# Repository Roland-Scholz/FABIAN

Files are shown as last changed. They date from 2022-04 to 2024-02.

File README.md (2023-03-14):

# Fa Bi An
FAbulous BInary ANihilator

A simple Z80 based CP/M system. You'll find here:

- KiCad files for the pcb
- 6-chip Z80 hardware
- 64KB static RAM
- 8/16/32KB (EP)ROM, here a 2764A version is used (8KB, 12,5V pgm voltage)
- 68681 double UART operating at 115200 baud
- one serial line connects to a VT100 terminal, the 2nd one to the CP/M disk server (two TTL to RS232 converters needed)
- GAL 16V8 providing glue logic (fabian.pld, connect PIN 5 and 15 with a pice of wire)
- WinCUPL https://www.microchip.com/en-us/products/fpgas-and-plds/spld-cplds/pld-design-resources)
- CP/M-2.2 and simple BIOS source code (CP/M at $E400, BIOS at $FA00)
- Windows based build files
- Serial CP/M disk server written in Java
- 8 output pins (7 usable, OP7 toggels ROM on/off)
- 6 input pins
- I have some PCBs left, write to rolandscholz@gmx.de if you want one

FabianPCB
FabianPCBbottom
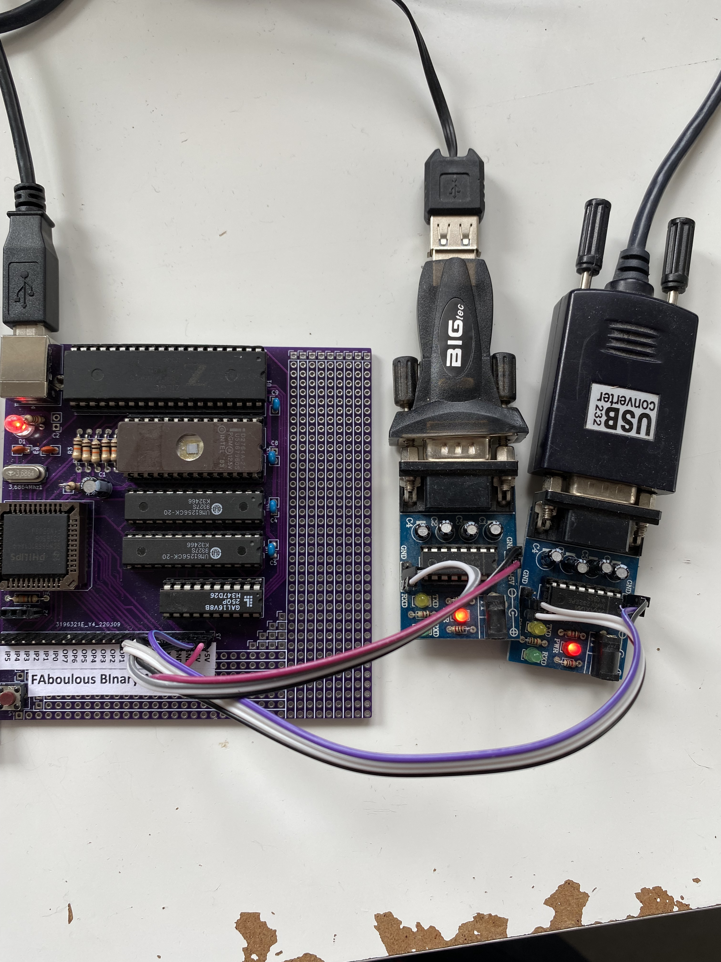
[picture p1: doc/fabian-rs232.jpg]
FabianRS232

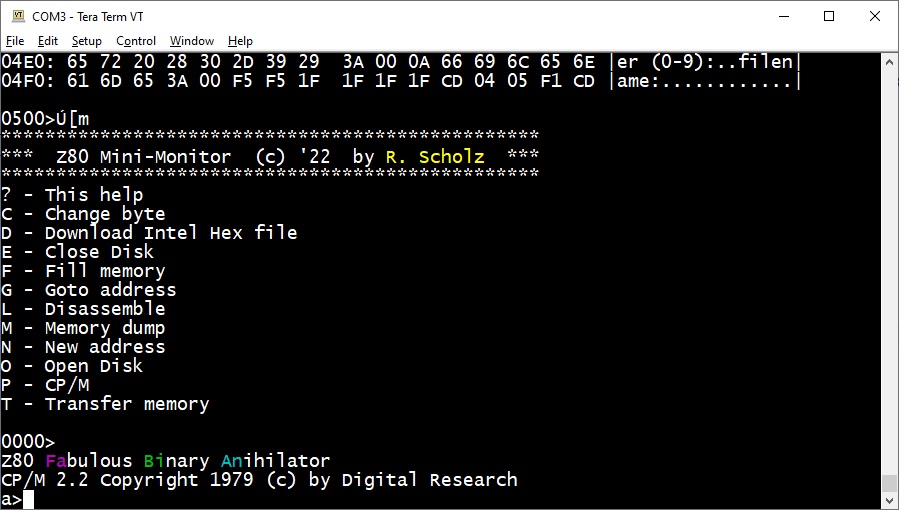
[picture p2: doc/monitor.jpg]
Monitor

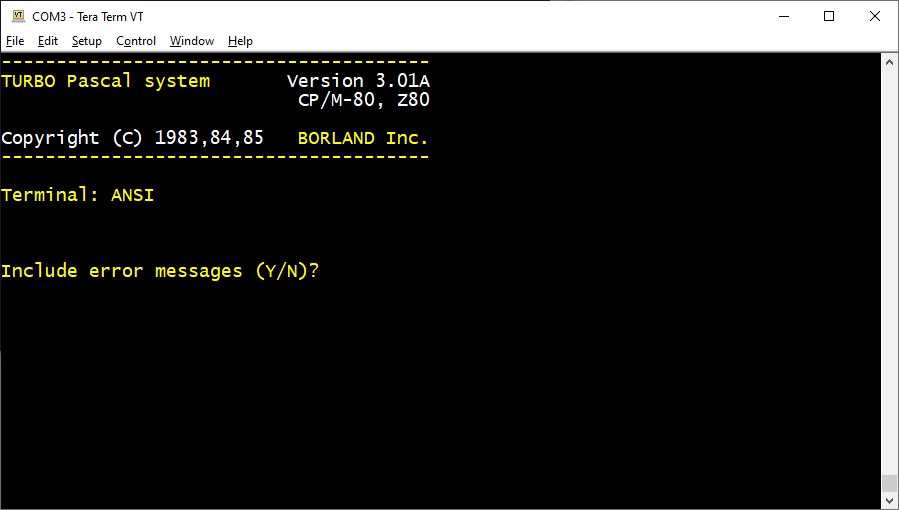
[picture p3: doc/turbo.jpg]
Turbo


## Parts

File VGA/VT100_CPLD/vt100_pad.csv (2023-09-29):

Release 8.1i - Fit P.20131013
Copyright(c) 1995-2003 Xilinx Inc. All rights reserved
9-24-2023 11:05PM
NOTE: This file is designed to be imported into a spreadsheet program
such as Microsoft Excel for viewing | printing and sorting. The comma ' | '
character is used as the data field separator.
This file is also designed to support parsing.
Input file: vt100.ngd
output file: vt100_pad.csv
Part type: xc9536
Speed grade: -15
Package: pc44
Pinout by Pin Number:
----- | ----- | ----- | ----- | ----- | ----- | ----- | ----- | ----- | -----
Pin Number | Signal Name | Pin Usage | Pin Name | Direction | IO Standard | IO Bank Number | {blank} | Slew Rate | Termination | {blank} | Voltage | Constraint
P1 | HSYNC | I/O | I/O | BIDIR
P2 | A15 | I | I/O | INPUT
P3 | WR | I | I/O | INPUT
P4 | RD | I | I/O | INPUT
P5 | pclk | GCK/I | I/O/GCK1
P6 | LOADDAT | I/O | I/O/GCK2 | BIDIR
P7 | LOADCOL | I/O | I/O/GCK3 | BIDIR
P8 | LOADAD | O | I/O | OUTPUT
P9 | CCLK | I/O | I/O | BIDIR
P10 | GND |  | GND
P11 | DE | I | I/O | INPUT
P12 | HS | I | I/O | INPUT
P13 | VS | I | I/O | INPUT
P14 | LOADSR | I/O | I/O | BIDIR
P15 | TDI |  | TDI
P16 | TMS |  | TMS
P17 | TCK |  | TCK
P18 | CRTCOE | O | I/O | OUTPUT
P19 | WE_RAM | O | I/O | OUTPUT
P20 | LOADCHR | I/O | I/O | BIDIR
P21 | VCC |  | VCCINT
P22 | CHAROE | O | I/O | OUTPUT
P23 | GND |  | GND
P24 | DISPEN | I/O | I/O | BIDIR
P25 | OE_ADR | O | I/O | OUTPUT
P26 | LOADCOLB | I/O | I/O | BIDIR
P27 | OE_DAT | O | I/O | OUTPUT
P28 | OE_RAM | O | I/O | OUTPUT
P29 | T0 | I | I/O | INPUT
P30 | TDO |  | TDO
P31 | GND |  | GND
P32 | VCC |  | VCCIO
P33 | TIE |  | I/O
P34 | TIE |  | I/O
P35 | TIE |  | I/O
P36 | TIE |  | I/O
P37 | TIE |  | I/O
P38 | TIE |  | I/O
P39 | TIE |  | I/O/GSR
P40 | TIE |  | I/O/GTS2
P41 | VCC |  | VCCINT
P42 | LCHRLINE | I/O | I/O/GTS1 | BIDIR
P43 | PIXCLKO | O | I/O | OUTPUT
P44 | VSYNC | I/O | I/O | BIDIR
To preserve the pinout above for future design iterations in
Project Navigator simply execute the (Lock Pins) process
located under the (Implement Design) process in a toolbox named
(Optional Implementation Tools) or invoke PIN2UCF from the
command line. The location constraints will be written into your
specified UCF file

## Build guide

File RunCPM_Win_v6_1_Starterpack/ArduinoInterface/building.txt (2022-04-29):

* LED.ASM (standard CP/M asm command):

A> asm led
A> load led

* LED.BAS (MBASIC v5.21):

A> mbasic led.bas

* LED.C (Hi-Tech C v3.09):

A> c -v led.c

* LED.PAS (Turbo Pascal v3.0):

A> turbo
   r
   led.pas

* PHOTO.C (Hi-Tech C v3.09):

A> c -v photo.c

* PHOTO.PAS (Turbo Pascal v3.0):

A> turbo
   r
   photo.pas

* PHOTOLED.4TH (DX-Forth v4.10):

A> dx
   include photoled.4th
   200 run

---------------
Important note:
---------------
If you experience any problems building any of the examples,
first make sure the EOL (end of line) in source files is set
to CRLF and not LF.
Git likes to change default EOL on checkout in Posix systems
(Linux, BSD, Mac OS X, etc).

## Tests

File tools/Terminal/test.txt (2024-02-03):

COM8 Standardmäßgige Seriell-über-Bluetooth-Verbindung (COM8)
COM9 Standardmäßgige Seriell-über-Bluetooth-Verbindung (COM9)
COM12 Standardmäßgige Seriell-über-Bluetooth-Verbindung (COM12)
COM4 Prolific USB-to-Serial Comm Port (COM4)
java.io.FileNotFoundException: test.txt (Das System kann die angegebene Datei nicht finden)
	at java.io.FileInputStream.open0(Native Method)
	at java.io.FileInputStream.open(FileInputStream.java:195)
	at java.io.FileInputStream.<init>(FileInputStream.java:138)
	at java.io.FileInputStream.<init>(FileInputStream.java:93)
	at Terminal.doSend(Terminal.java:71)
	at Terminal.doOperation(Terminal.java:116)
	at Terminal.<init>(Terminal.java:134)
	at Terminal.main(Terminal.java:146)

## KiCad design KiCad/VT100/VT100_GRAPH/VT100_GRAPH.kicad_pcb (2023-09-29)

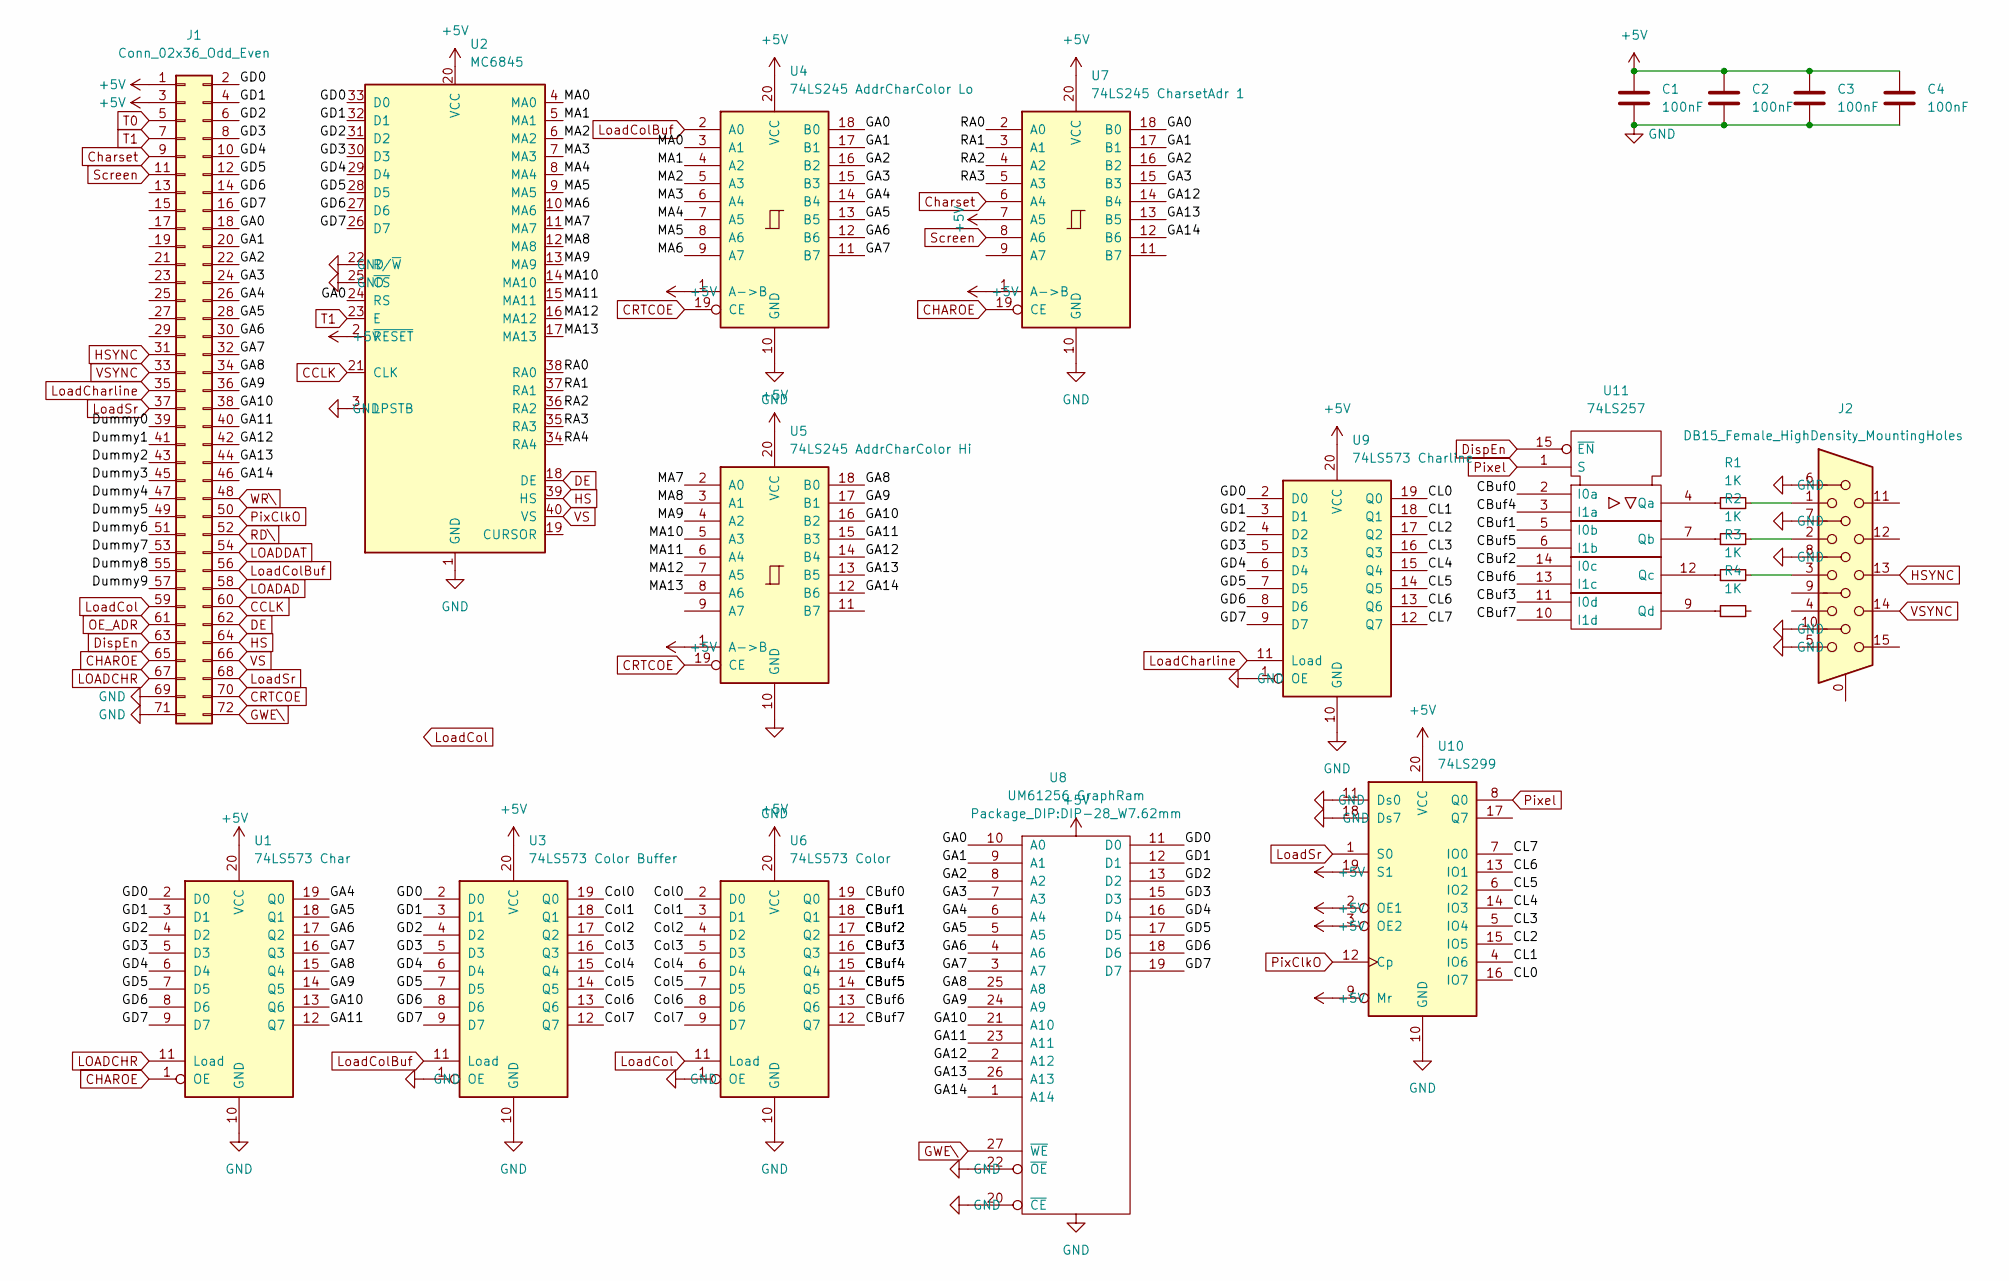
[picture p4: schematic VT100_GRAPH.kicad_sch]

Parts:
C1, C2, C3, C4: 100nF; C_Rect_L7.0mm_W2.0mm_P5.00mm
J1: Conn_02x36_Odd_Even; PinSocket_2x36_P2.54mm_Vertical
J2: DB15_Female_HighDensity_MountingHoles; DSUB-15-HD_Female_Horizontal_P2.29x1.98mm_EdgePinOffset3.03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
R1, R2, R3, R4: 1K; R_Axial_DIN0204_L3.6mm_D1.6mm_P1.90mm_Vertical
U1: 74LS573 Char; DIP-20_W7.62mm
U2: MC6845; DIP-40_W15.24mm
U3: 74LS573 Color Buffer; DIP-20_W7.62mm
U4: 74LS245 AddrCharColor Lo; DIP-20_W7.62mm
U5: 74LS245 AddrCharColor Hi; DIP-20_W7.62mm
U6: 74LS573 Color; DIP-20_W7.62mm
U7: 74LS245 CharsetAdr 1; DIP-20_W7.62mm
U8: UM61256 GraphRam; DIP-28_W7.62mm
U9: 74LS573 Charline; DIP-20_W7.62mm
U10: 74LS299; DIP-20_W7.62mm
U11: 74LS257; DIP-16_W7.62mm

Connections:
+5V: C1.1, C2.1, C3.1, C4.1, J1.1, J1.3, U1.20 (VCC), U2.2 (~RESET), U2.20 (VCC), U3.20 (VCC), U4.1 (A->B), U4.20 (VCC), U5.1 (A->B), U5.20 (VCC), U6.20 (VCC), U7.1 (A->B), U7.7 (A5), U7.20 (VCC), U8.28 (VCC), U9.20 (VCC), U10.2 (OE1), U10.3 (OE2), U10.9 (Mr), U10.19 (S1), U10.20 (VCC), U11.16 (VCC)
/CBuf0: U6.19 (Q0), U11.2 (I0a)
/CBuf1: U6.18 (Q1), U11.5 (I0b)
/CBuf2: U6.17 (Q2), U11.14 (I0c)
/CBuf3: U6.16 (Q3), U11.11 (I0d)
/CBuf4: U6.15 (Q4), U11.3 (I1a)
/CBuf5: U6.14 (Q5), U11.6 (I1b)
/CBuf6: U6.13 (Q6), U11.13 (I1c)
/CBuf7: U6.12 (Q7), U11.10 (I1d)
/CL0: U9.19 (Q0), U10.16 (IO7)
/CL1: U9.18 (Q1), U10.4 (IO6)
/CL2: U9.17 (Q2), U10.15 (IO5)
/CL3: U9.16 (Q3), U10.5 (IO4)
/CL4: U9.15 (Q4), U10.14 (IO3)
/CL5: U9.14 (Q5), U10.6 (IO2)
/CL6: U9.13 (Q6), U10.13 (IO1)
/CL7: U9.12 (Q7), U10.7 (IO0)
/Col0: U3.19 (Q0), U6.2 (D0)
/Col1: U3.18 (Q1), U6.3 (D1)
/Col2: U3.17 (Q2), U6.4 (D2)
/Col3: U3.16 (Q3), U6.5 (D3)
/Col4: U3.15 (Q4), U6.6 (D4)
/Col5: U3.14 (Q5), U6.7 (D5)
/Col6: U3.13 (Q6), U6.8 (D6)
/Col7: U3.12 (Q7), U6.9 (D7)
/Dummy0: J1.39
/Dummy1: J1.41
/Dummy2: J1.43
/Dummy3: J1.45
/Dummy4: J1.47
/Dummy5: J1.49
/Dummy6: J1.51
/Dummy7: J1.53
/Dummy8: J1.55
/Dummy9: J1.57
/GA0: J1.18, U2.24 (RS), U4.18 (B0), U7.18 (B0), U8.10 (A0)
/GA1: J1.20, U4.17 (B1), U7.17 (B1), U8.9 (A1)
/GA2: J1.22, U4.16 (B2), U7.16 (B2), U8.8 (A2)
/GA3: J1.24, U4.15 (B3), U7.15 (B3), U8.7 (A3)
/GA4: J1.26, U1.19 (Q0), U4.14 (B4), U8.6 (A4)
/GA5: J1.28, U1.18 (Q1), U4.13 (B5), U8.5 (A5)
/GA6: J1.30, U1.17 (Q2), U4.12 (B6), U8.4 (A6)
/GA7: J1.32, U1.16 (Q3), U4.11 (B7), U8.3 (A7)
/GA8: J1.34, U1.15 (Q4), U5.18 (B0), U8.25 (A8)
/GA9: J1.36, U1.14 (Q5), U5.17 (B1), U8.24 (A9)
/GA10: J1.38, U1.13 (Q6), U5.16 (B2), U8.21 (A10)
/GA11: J1.40, U1.12 (Q7), U5.15 (B3), U8.23 (A11)
/GA12: J1.42, U5.14 (B4), U7.14 (B4), U8.2 (A12)
/GA13: J1.44, U5.13 (B5), U7.13 (B5), U8.26 (A13)
/GA14: J1.46, U5.12 (B6), U7.12 (B6), U8.1 (A14)
/GD0: J1.2, U1.2 (D0), U2.33 (D0), U3.2 (D0), U8.11 (D0), U9.2 (D0)
/GD1: J1.4, U1.3 (D1), U2.32 (D1), U3.3 (D1), U8.12 (D1), U9.3 (D1)
/GD2: J1.6, U1.4 (D2), U2.31 (D2), U3.4 (D2), U8.13 (D2), U9.4 (D2)
/GD3: J1.8, U1.5 (D3), U2.30 (D3), U3.5 (D3), U8.15 (D3), U9.5 (D3)
/GD4: J1.10, U1.6 (D4), U2.29 (D4), U3.6 (D4), U8.16 (D4), U9.6 (D4)
/GD5: J1.12, U1.7 (D5), U2.28 (D5), U3.7 (D5), U8.17 (D5), U9.7 (D5)
/GD6: J1.14, U1.8 (D6), U2.27 (D6), U3.8 (D6), U8.18 (D6), U9.8 (D6)
/GD7: J1.16, U1.9 (D7), U2.26 (D7), U3.9 (D7), U8.19 (D7), U9.9 (D7)
/MA0: U2.4 (MA0), U4.3 (A1)
/MA1: U2.5 (MA1), U4.4 (A2)
/MA2: U2.6 (MA2), U4.5 (A3)
/MA3: U2.7 (MA3), U4.6 (A4)
/MA4: U2.8 (MA4), U4.7 (A5)
/MA5: U2.9 (MA5), U4.8 (A6)
/MA6: U2.10 (MA6), U4.9 (A7)
/MA7: U2.11 (MA7), U5.2 (A0)
/MA8: U2.12 (MA8), U5.3 (A1)
/MA9: U2.13 (MA9), U5.4 (A2)
/MA10: U2.14 (MA10), U5.5 (A3)
/MA11: U2.15 (MA11), U5.6 (A4)
/MA12: U2.16 (MA12), U5.7 (A5)
/MA13: U2.17 (MA13), U5.8 (A6)
/RA0: U2.38 (RA0), U7.2 (A0)
/RA1: U2.37 (RA1), U7.3 (A1)
/RA2: U2.36 (RA2), U7.4 (A2)
/RA3: U2.35 (RA3), U7.5 (A3)
/RA4: U2.34 (RA4)
CCLK: J1.60, U2.21 (CLK)
CHAROE: J1.65, U1.1 (OE), U7.19 (CE)
CRTCOE: J1.70, U4.19 (CE), U5.19 (CE)
Charset: J1.9, U7.6 (A4)
DE: J1.62, U2.18 (DE)
DispEn: J1.63, U11.15 (~EN)
GND: C1.2, C2.2, C3.2, C4.2, J1.69, J1.71, J2.5, J2.6, J2.7, J2.8, J2.10, U1.10 (GND), U2.1 (GND), U2.3 (LPSTB), U2.22 (R/~W), U2.25 (~CS), U3.1 (OE), U3.10 (GND), U4.10 (GND), U5.10 (GND), U6.1 (OE), U6.10 (GND), U7.10 (GND), U8.14 (GND), U8.20 (~CE), U8.22 (~OE), U9.1 (OE), U9.10 (GND), U10.10 (GND), U10.11 (Ds0), U10.18 (Ds7), U11.8 (GND)
GWE\: J1.72, U8.27 (~WE)
HS: J1.64, U2.39 (HS)
HSYNC: J1.31, J2.13
LOADAD: J1.58
LOADCHR: J1.67, U1.11 (Load)
LOADDAT: J1.54
LoadCharline: J1.35, U9.11 (Load)
LoadCol: J1.59, U6.11 (Load)
LoadColBuf: J1.56, U3.11 (Load), U4.2 (A0)
LoadSr: J1.37, J1.68, U10.1 (S0)
unnamed: J2.1, R1.2
unnamed: J2.2, R2.2
unnamed: J2.3, R3.2
unnamed: R1.1, U11.4 (Qa)
unnamed: R2.1, U11.7 (Qb)
unnamed: R3.1, U11.12 (Qc)
unnamed: R4.1, U11.9 (Qd)
OE_ADR: J1.61
PixClkO: J1.50, U10.12 (Cp)
Pixel: U10.8 (Q0), U11.1 (S)
RD\: J1.52
Screen: J1.11, U7.8 (A6)
T0: J1.5
T1: J1.7, U2.23 (E)
VS: J1.66, U2.40 (VS)
VSYNC: J1.33, J2.14
WR\: J1.48

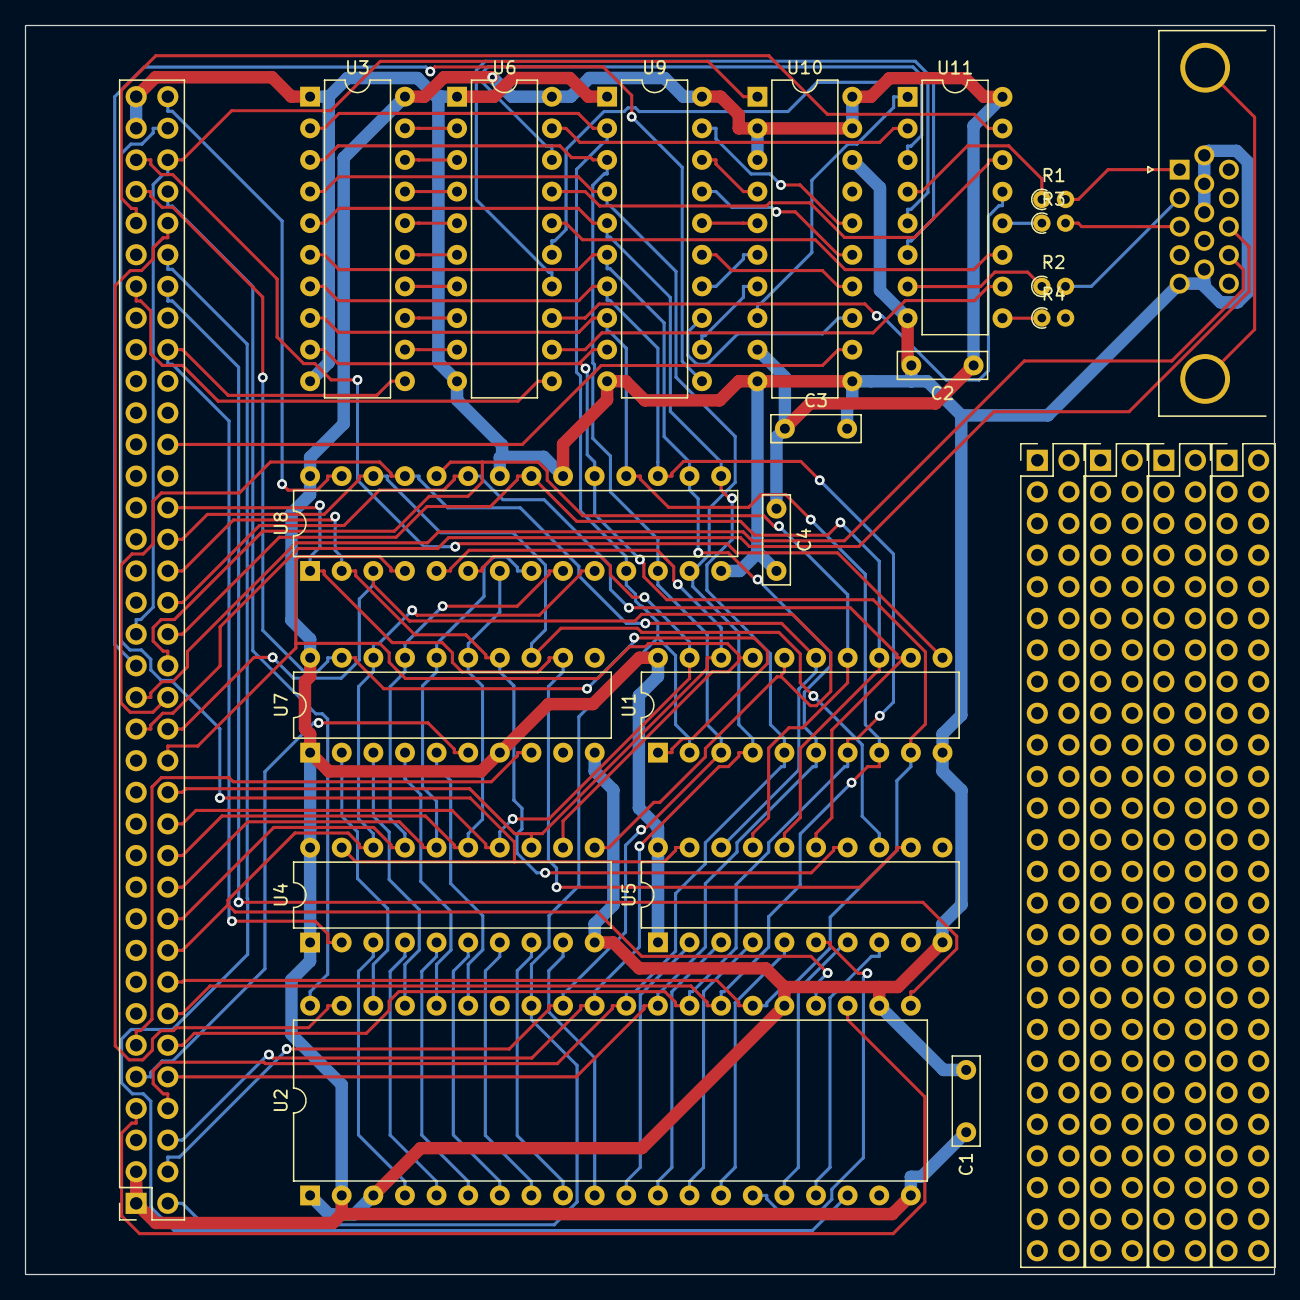
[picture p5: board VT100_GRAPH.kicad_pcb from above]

Board: 2 copper layers, 100.3 x 100.3 mm, 21 parts (0 on the bottom side), 94 nets.

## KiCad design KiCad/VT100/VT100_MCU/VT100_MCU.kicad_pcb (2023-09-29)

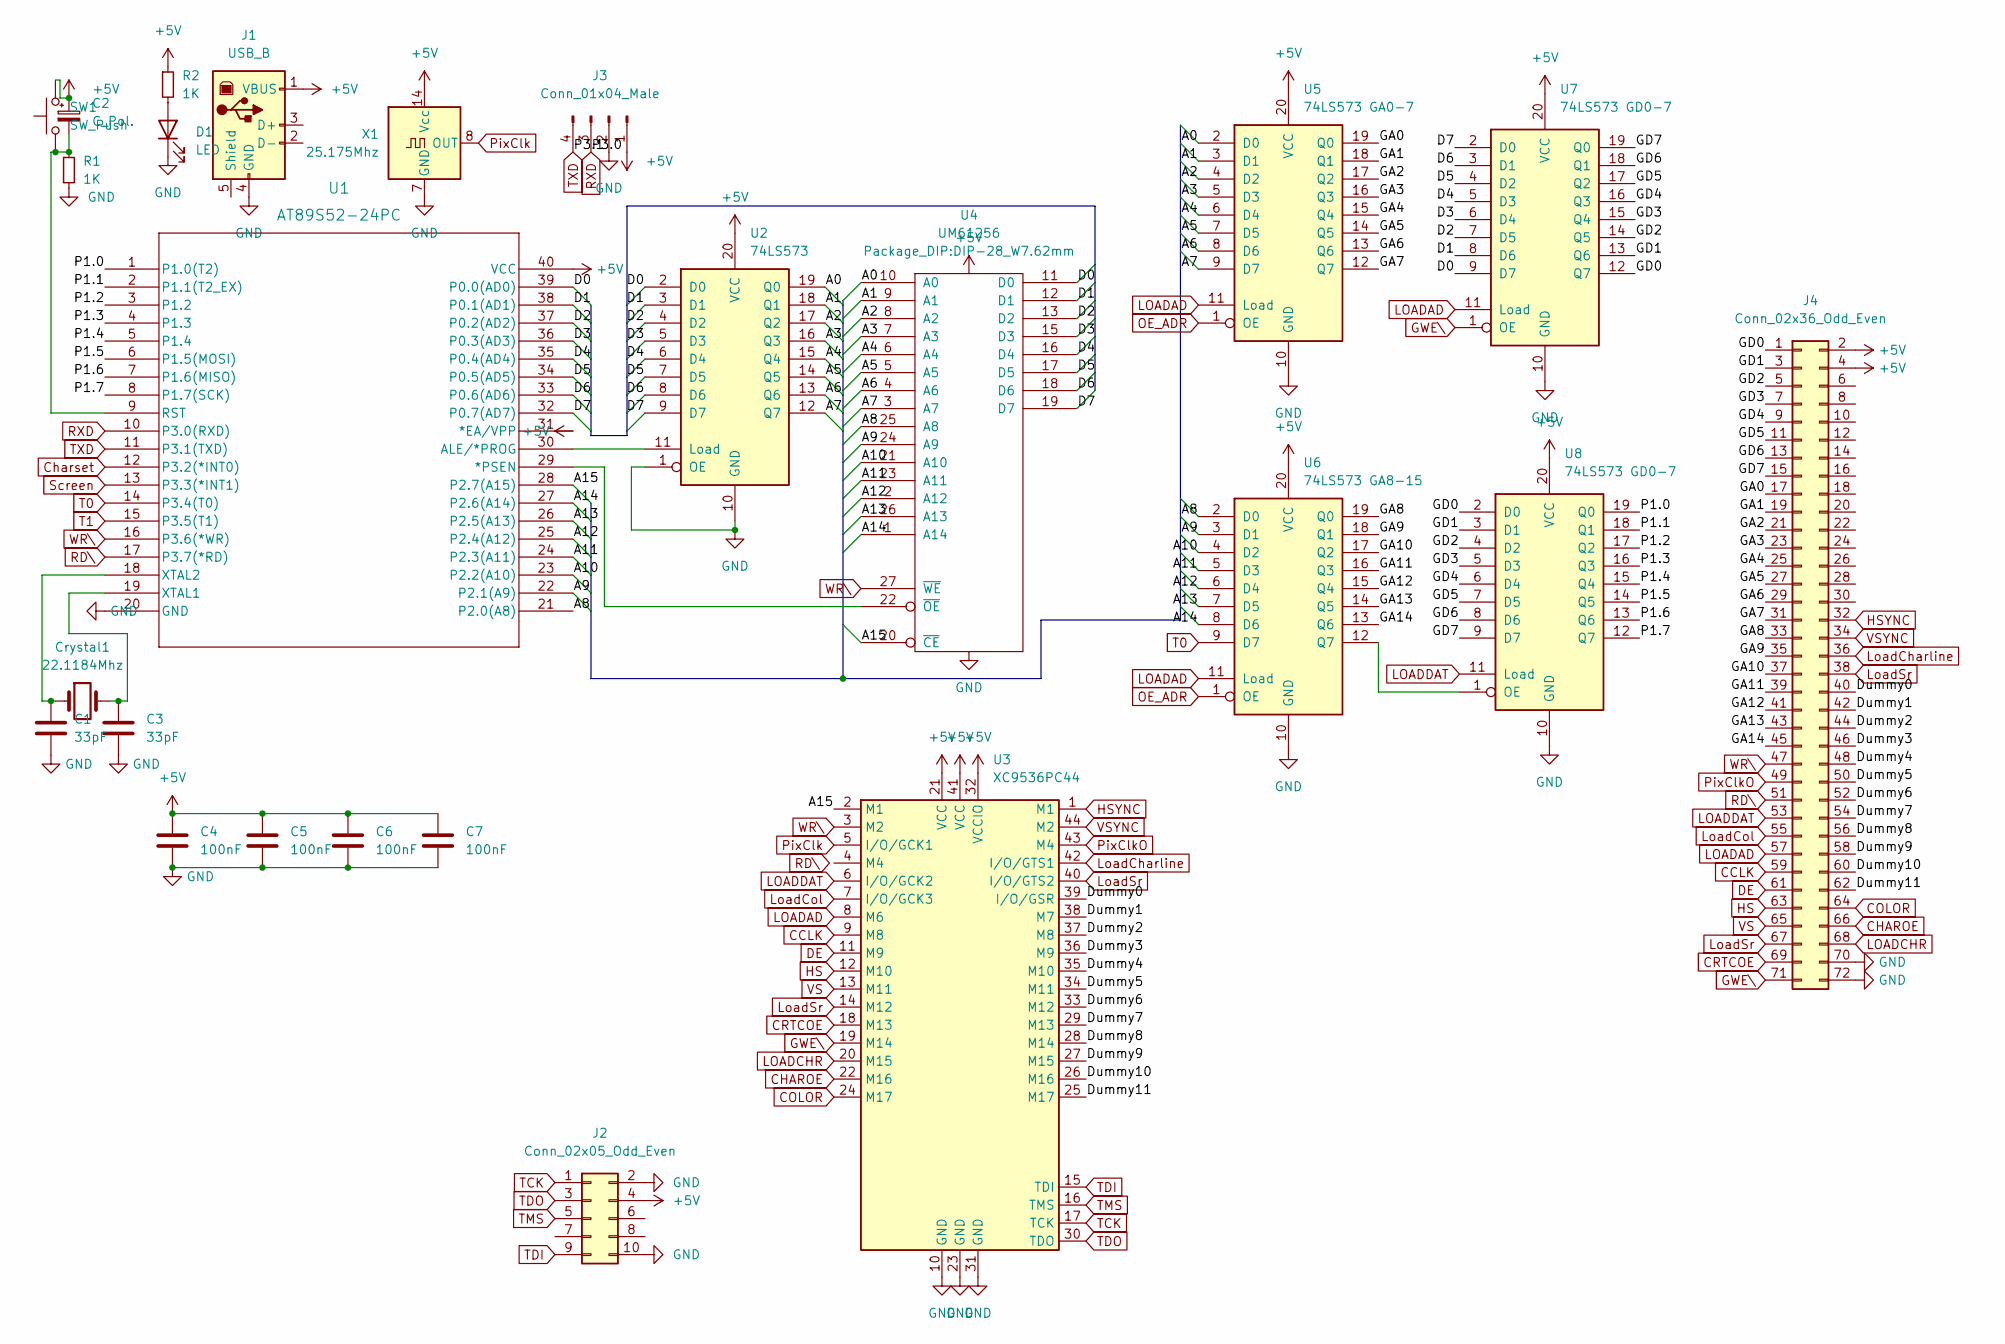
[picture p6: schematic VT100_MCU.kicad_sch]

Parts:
C1, C3: 33pF; PinHeader_1x02_P2.54mm_Vertical
C2: C_Pol.; CP_Radial_D5.0mm_P2.50mm
C4, C5, C6, C7: 100nF; PinHeader_1x02_P2.54mm_Vertical
Crystal1: 22.1184Mhz; Crystal_HC18-U_Vertical
D1: LED; LED_D5.0mm
J1: USB_B; USB_B_Lumberg_2411_02_Horizontal
J2: Conn_02x05_Odd_Even; PinHeader_2x05_P2.54mm_Vertical
J3: Conn_01x04_Male; PinHeader_1x04_P2.54mm_Vertical
J4: Conn_02x36_Odd_Even; PinSocket_2x36_P2.54mm_Horizontal
R1, R2: 1K; R_Axial_DIN0204_L3.6mm_D1.6mm_P1.90mm_Vertical
SW1: SW_Push; C_Rect_L7.5mm_W6.5mm_P5.00mm
U1: AT89S52-24PC; DIP-40_W15.24mm
U2: 74LS573; DIP-20_W7.62mm
U3: XC9536PC44; PLCC-44_THT-Socket
U4: UM61256; DIP-28_W7.62mm
U5: 74LS573 GA0-7; DIP-20_W7.62mm
U6: 74LS573 GA8-15; DIP-20_W7.62mm
U7, U8: 74LS573 GD0-7; DIP-20_W7.62mm
X1: 25.175Mhz; Oscillator_DIP-14

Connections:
+5V: C2.1, C4.1, C5.1, C6.1, C7.1, J1.1 (VBUS), J2.4, J3.1, J4.2, J4.4, R2.1, SW1.2, U1.31 (*EA/VPP), U1.40 (VCC), U2.20 (VCC), U3.21 (VCC), U3.32 (VCCIO), U3.41 (VCC), U4.28 (VCC), U5.20 (VCC), U6.20 (VCC), U7.20 (VCC), U8.20 (VCC), X1.14 (Vcc)
/A0: U2.19 (Q0), U4.10 (A0), U5.2 (D0)
/A1: U2.18 (Q1), U4.9 (A1), U5.3 (D1)
/A2: U2.17 (Q2), U4.8 (A2), U5.4 (D2)
/A3: U2.16 (Q3), U4.7 (A3), U5.5 (D3)
/A4: U2.15 (Q4), U4.6 (A4), U5.6 (D4)
/A5: U2.14 (Q5), U4.5 (A5), U5.7 (D5)
/A6: U2.13 (Q6), U4.4 (A6), U5.8 (D6)
/A7: U2.12 (Q7), U4.3 (A7), U5.9 (D7)
/A8: U1.21 (P2.0(A8)), U4.25 (A8), U6.2 (D0)
/A9: U1.22 (P2.1(A9)), U4.24 (A9), U6.3 (D1)
/A10: U1.23 (P2.2(A10)), U4.21 (A10), U6.4 (D2)
/A11: U1.24 (P2.3(A11)), U4.23 (A11), U6.5 (D3)
/A12: U1.25 (P2.4(A12)), U4.2 (A12), U6.6 (D4)
/A13: U1.26 (P2.5(A13)), U4.26 (A13), U6.7 (D5)
/A14: U1.27 (P2.6(A14)), U4.1 (A14), U6.8 (D6)
/A15: U1.28 (P2.7(A15)), U3.2 (M1), U4.20 (~CE)
/D0: U1.39 (P0.0(AD0)), U2.2 (D0), U4.11 (D0), U7.9 (D7)
/D1: U1.38 (P0.1(AD1)), U2.3 (D1), U4.12 (D1), U7.8 (D6)
/D2: U1.37 (P0.2(AD2)), U2.4 (D2), U4.13 (D2), U7.7 (D5)
/D3: U1.36 (P0.3(AD3)), U2.5 (D3), U4.15 (D3), U7.6 (D4)
/D4: U1.35 (P0.4(AD4)), U2.6 (D4), U4.16 (D4), U7.5 (D3)
/D5: U1.34 (P0.5(AD5)), U2.7 (D5), U4.17 (D5), U7.4 (D2)
/D6: U1.33 (P0.6(AD6)), U2.8 (D6), U4.18 (D6), U7.3 (D1)
/D7: U1.32 (P0.7(AD7)), U2.9 (D7), U4.19 (D7), U7.2 (D0)
/Dummy0: J4.40, U3.39 (I/O/GSR)
/Dummy1: J4.42, U3.38 (M7)
/Dummy2: J4.44, U3.37 (M8)
/Dummy3: J4.46, U3.36 (M9)
/Dummy4: J4.48, U3.35 (M10)
/Dummy5: J4.50, U3.34 (M11)
/Dummy6: J4.52, U3.33 (M12)
/Dummy7: J4.54, U3.29 (M13)
/Dummy8: J4.56, U3.28 (M14)
/Dummy9: J4.58, U3.27 (M15)
/Dummy10: J4.60, U3.26 (M16)
/GA0: J4.17, U5.19 (Q0)
/GA1: J4.19, U5.18 (Q1)
/GA2: J4.21, U5.17 (Q2)
/GA3: J4.23, U5.16 (Q3)
/GA4: J4.25, U5.15 (Q4)
/GA5: J4.27, U5.14 (Q5)
/GA6: J4.29, U5.13 (Q6)
/GA7: J4.31, U5.12 (Q7)
/GA8: J4.33, U6.19 (Q0)
/GA9: J4.35, U6.18 (Q1)
/GA10: J4.37, U6.17 (Q2)
/GA11: J4.39, U6.16 (Q3)
/GA12: J4.41, U6.15 (Q4)
/GA13: J4.43, U6.14 (Q5)
/GA14: J4.45, U6.13 (Q6)
/GD0: J4.1, U7.12 (Q7), U8.2 (D0)
/GD1: J4.3, U7.13 (Q6), U8.3 (D1)
/GD2: J4.5, U7.14 (Q5), U8.4 (D2)
/GD3: J4.7, U7.15 (Q4), U8.5 (D3)
/GD4: J4.9, U7.16 (Q3), U8.6 (D4)
/GD5: J4.11, U7.17 (Q2), U8.7 (D5)
/GD6: J4.13, U7.18 (Q1), U8.8 (D6)
/GD7: J4.15, U7.19 (Q0), U8.9 (D7)
/P1.0: U1.1 (P1.0(T2)), U8.19 (Q0)
/P1.1: U1.2 (P1.1(T2_EX)), U8.18 (Q1)
/P1.2: U1.3 (P1.2), U8.17 (Q2)
/P1.3: U1.4 (P1.3), U8.16 (Q3)
/P1.4: U1.5 (P1.4), U8.15 (Q4)
/P1.5: U1.6 (P1.5(MOSI)), U8.14 (Q5)
/P1.6: U1.7 (P1.6(MISO)), U8.13 (Q6)
/P1.7: U1.8 (P1.7(SCK)), U8.12 (Q7)
CCLK: J4.59, U3.9 (M8)
CHAROE: J4.66, U3.22 (M16)
CRTCOE: J4.69, U3.18 (M13)
Charset: J4.10, U1.12 (P3.2(*INT0))
DE: J4.61, U3.11 (M9)
DispEn: J4.64, U3.24 (M17)
GND: C1.2, C3.2, C4.2, C5.2, C6.2, C7.2, D1.1 (K), J1.4 (GND), J2.2, J2.10, J3.2, J4.70, J4.72, R1.2, U1.20 (GND), U2.1 (OE), U2.10 (GND), U3.10 (GND), U3.23 (GND), U3.31 (GND), U4.14 (GND), U5.10 (GND), U6.10 (GND), U7.10 (GND), U8.10 (GND), X1.7 (GND)
GWE\: J4.71, U3.19 (M14), U7.1 (OE)
HS: J4.63, U3.12 (M10)
HSYNC: J4.32, U3.1 (M1)
LOADAD: J4.57, U3.8 (M6), U5.11 (Load), U6.11 (Load), U7.11 (Load)
LOADCHR: J4.68, U3.20 (M15)
LOADDAT: J4.53, U3.6 (I/O/GCK2), U8.11 (Load)
LoadCharline: J4.36, U3.42 (I/O/GTS1)
LoadCol: J4.55, U3.7 (I/O/GCK3)
LoadSr: J4.38, J4.67, U3.14 (M12), U3.40 (I/O/GTS2)
unnamed: C1.1, Crystal1.1, U1.18 (XTAL2)
unnamed: C2.2, R1.1, SW1.1, U1.9 (RST)
unnamed: C3.1, Crystal1.2, U1.19 (XTAL1)
unnamed: D1.2 (A), R2.2
unnamed: U1.29 (*PSEN), U4.22 (~OE)
unnamed: U1.30 (ALE/*PROG), U2.11 (Load)
unnamed: U6.12 (Q7), U8.1 (OE)
PixClk: U3.5 (I/O/GCK1), X1.8 (OUT)
PixClkO: J4.49, U3.43 (M4)
RD\: J4.51, U1.17 (P3.7(*RD)), U3.4 (M4)
RXD: J3.3, U1.10 (P3.0(RXD))
Screen: J4.12, U1.13 (P3.3(*INT1))
T0: J4.6, U1.14 (P3.4(T0)), U6.9 (D7)
T1: J4.8, U1.15 (P3.5(T1))
TCK: J2.1, U3.17 (TCK)
TDI: J2.9, U3.15 (TDI)
TDO: J2.3, U3.30 (TDO)
TMS: J2.5, U3.16 (TMS)
TXD: J3.4, U1.11 (P3.1(TXD))
VS: J4.65, U3.13 (M11)
VSYNC: J4.34, U3.44 (M2)
WR\: J4.47, U1.16 (P3.6(*WR)), U3.3 (M2), U4.27 (~WE)

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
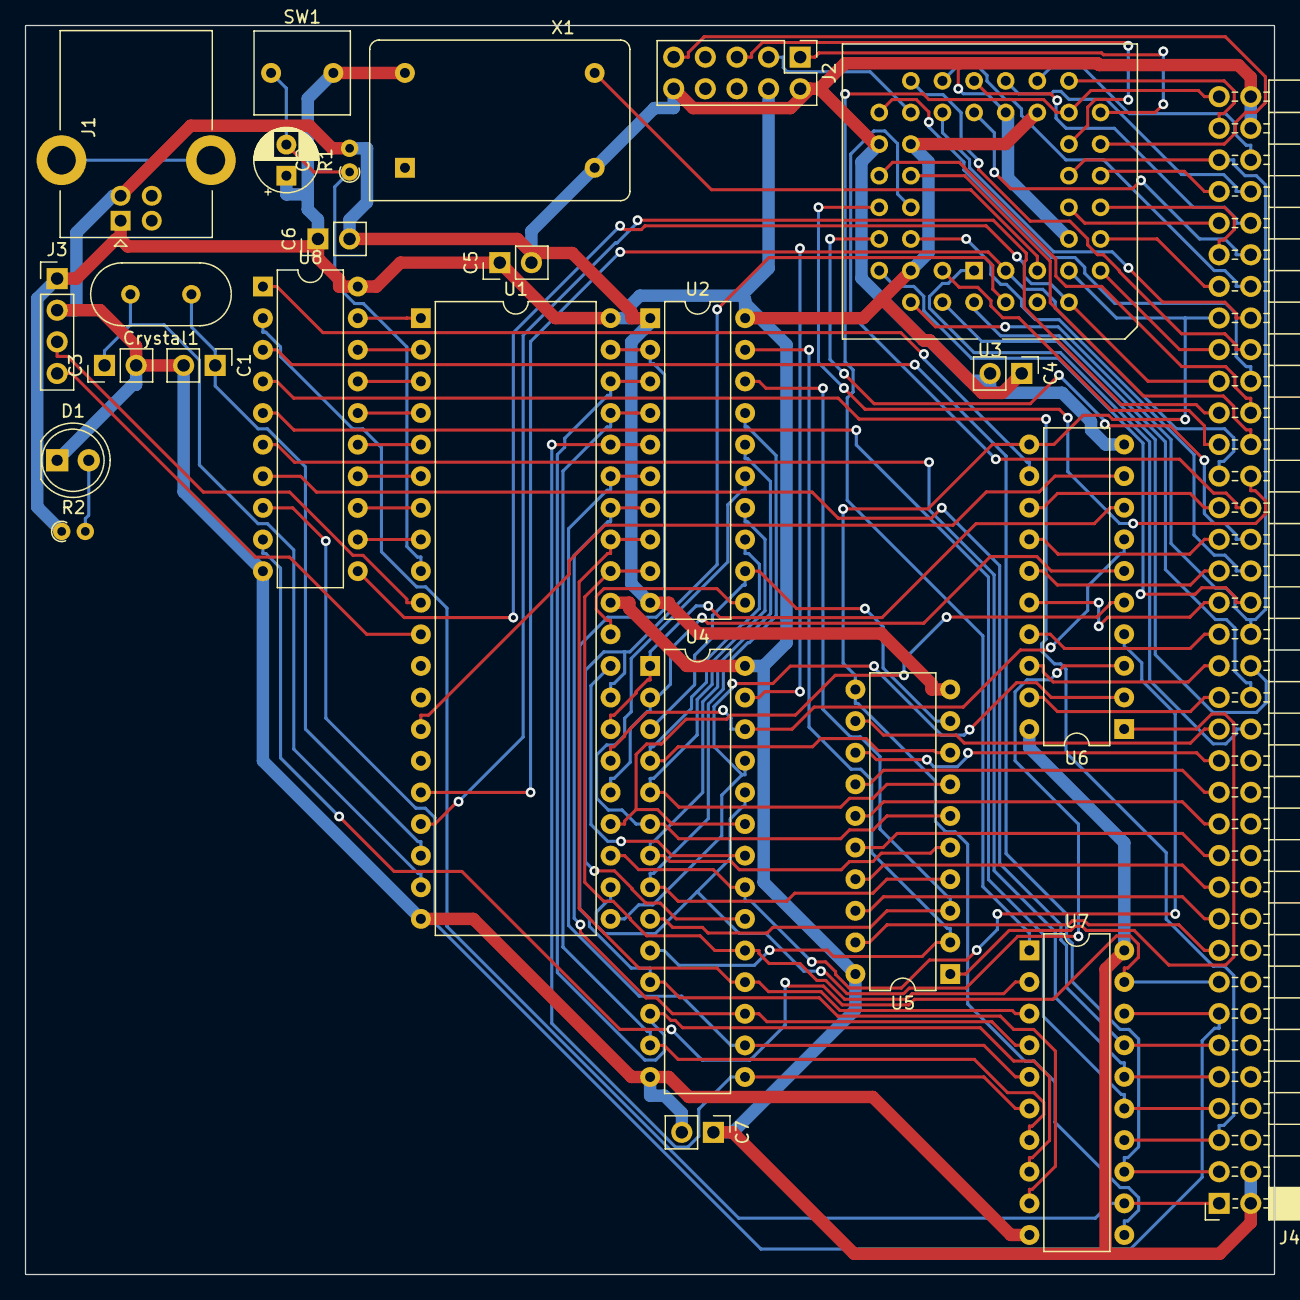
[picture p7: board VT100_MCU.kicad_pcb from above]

Board: 2 copper layers, 100.3 x 100.3 mm, 25 parts (0 on the bottom side), 106 nets.

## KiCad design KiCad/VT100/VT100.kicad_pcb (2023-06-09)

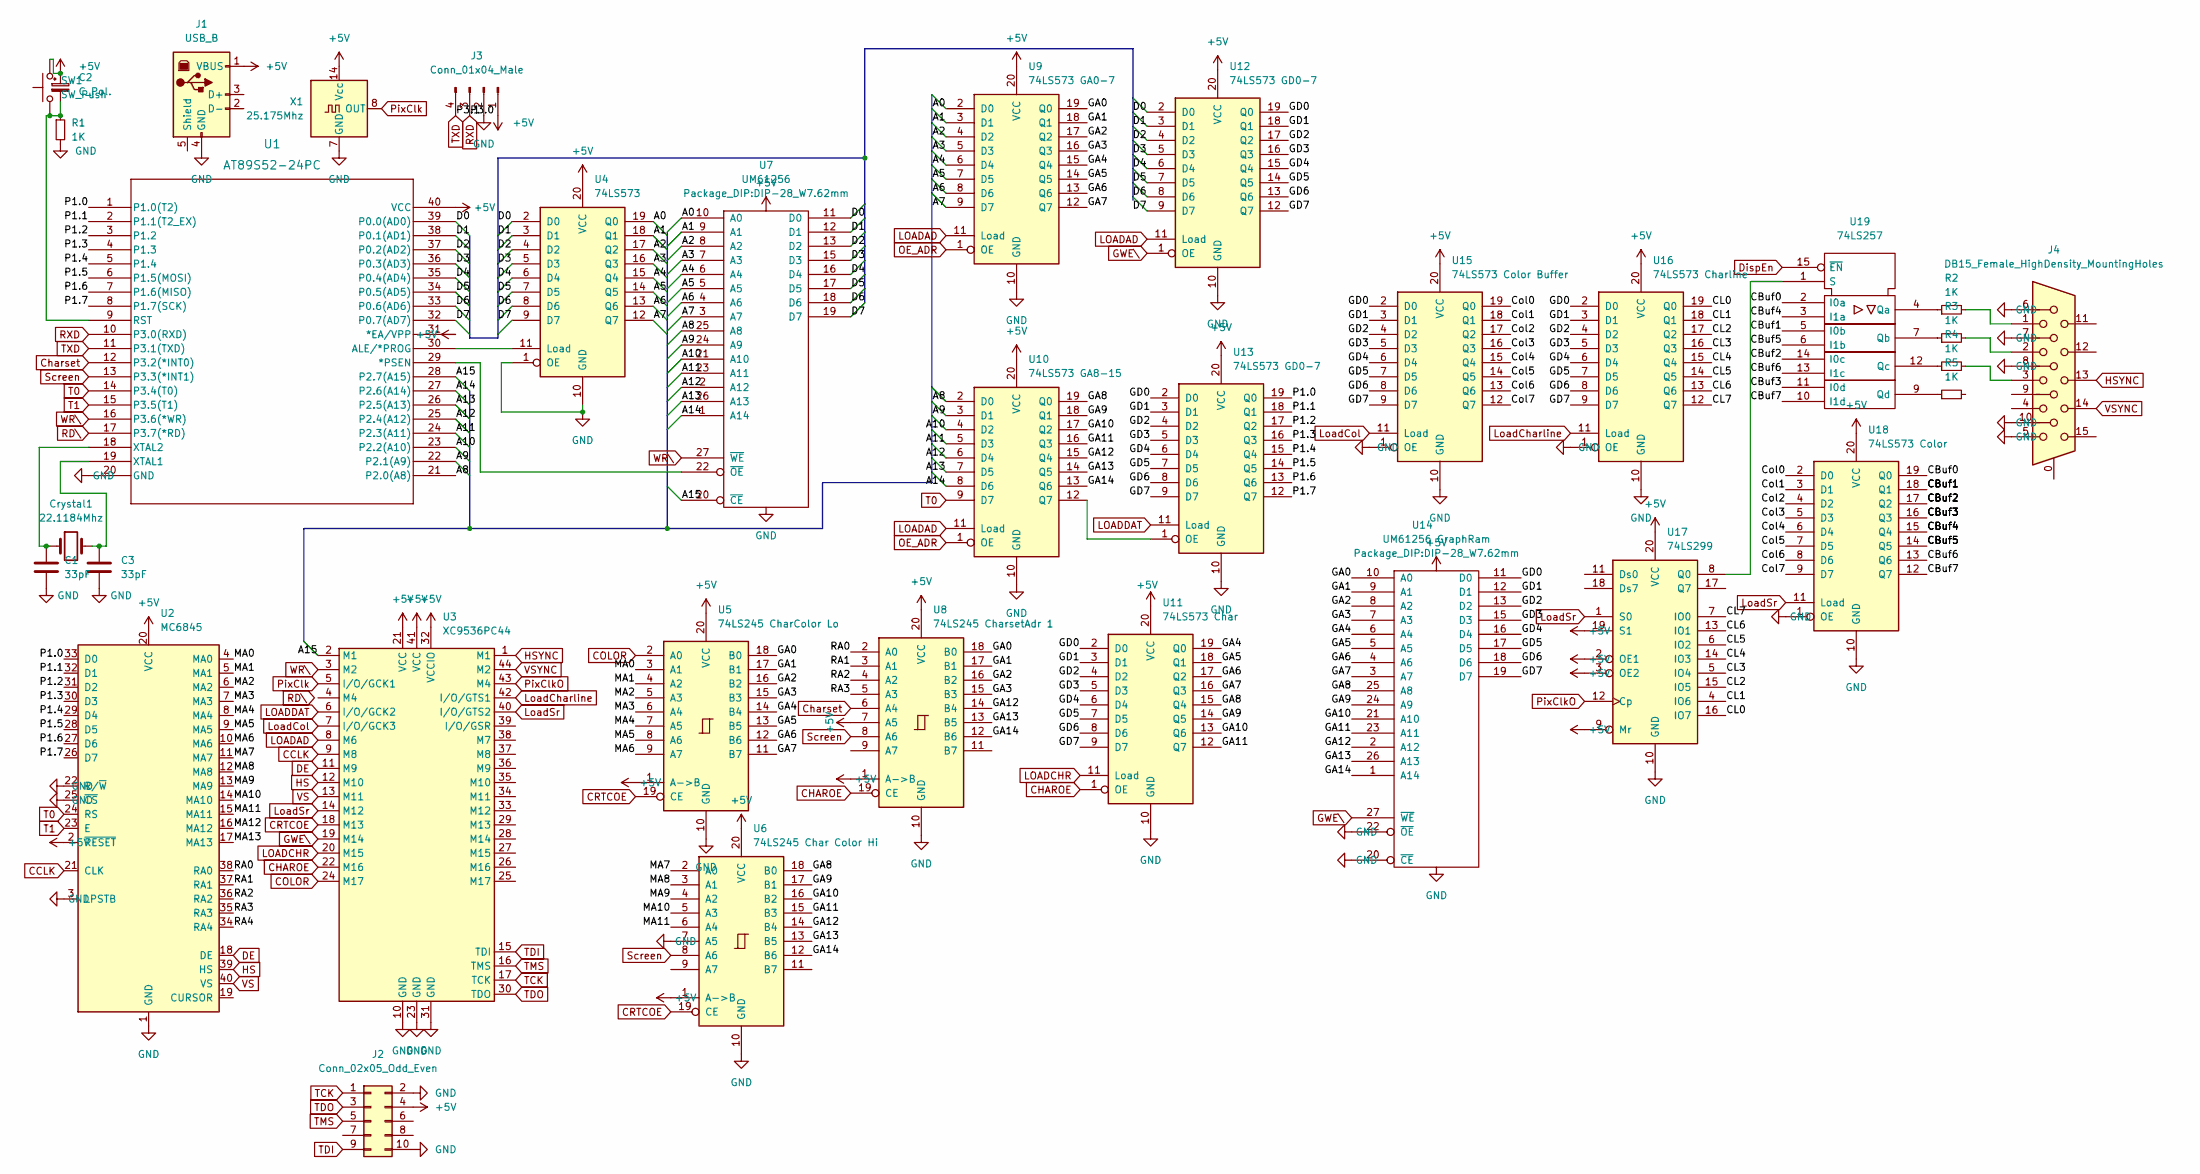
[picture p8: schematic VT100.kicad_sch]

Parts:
C1, C3: 33pF; PinHeader_1x02_P2.54mm_Vertical
C2: C_Pol.; CP_Radial_D5.0mm_P2.50mm
Crystal1: 22.1184Mhz; Crystal_HC18-U_Vertical
J1: USB_B; USB_B_Lumberg_2411_02_Horizontal
J2: Conn_02x05_Odd_Even; PinHeader_2x05_P2.54mm_Vertical
J3: Conn_01x04_Male; PinHeader_1x04_P2.54mm_Vertical
J4: DB15_Female_HighDensity_MountingHoles; DSUB-15-HD_Female_Horizontal_P2.29x1.98mm_EdgePinOffset3.03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
R1, R2, R3, R4, R5: 1K; R_Axial_DIN0204_L3.6mm_D1.6mm_P1.90mm_Vertical
SW1: SW_Push; C_Rect_L7.5mm_W6.5mm_P5.00mm
U1: AT89S52-24PC; DIP-40_W15.24mm
U2: MC6845; DIP-40_W15.24mm
U3: XC9536PC44; PLCC-44_THT-Socket
U4: 74LS573; DIP-20_W7.62mm
U5: 74LS245 CharColor Lo; DIP-20_W7.62mm
U6: 74LS245 Char Color Hi; DIP-20_W7.62mm
U7: UM61256; DIP-28_W7.62mm
U8: 74LS245 CharsetAdr 1; DIP-20_W7.62mm
U9: 74LS573 GA0-7; DIP-20_W7.62mm
U10: 74LS573 GA8-15; DIP-20_W7.62mm
U11: 74LS573 Char; DIP-20_W7.62mm
U12, U13: 74LS573 GD0-7; DIP-20_W7.62mm
U14: UM61256 GraphRam; DIP-28_W7.62mm
U15: 74LS573 Color Buffer; DIP-20_W7.62mm
U16: 74LS573 Charline; DIP-20_W7.62mm
U17: 74LS299; DIP-20_W7.62mm
U18: 74LS573 Color; DIP-20_W7.62mm
U19: 74LS257; DIP-16_W7.62mm
X1: 25.175Mhz; Oscillator_DIP-14

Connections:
+5V: C2.1, J1.1 (VBUS), J2.4, J3.1, SW1.2, U1.31 (*EA/VPP), U1.40 (VCC), U2.2 (~RESET), U2.20 (VCC), U3.21 (VCC), U3.32 (VCCIO), U3.41 (VCC), U4.20 (VCC), U5.1 (A->B), U5.20 (VCC), U6.1 (A->B), U6.20 (VCC), U7.28 (VCC), U8.1 (A->B), U8.7 (A5), U8.20 (VCC), U9.20 (VCC), U10.20 (VCC), U11.20 (VCC), U12.20 (VCC), U13.20 (VCC), U14.28 (VCC), U15.20 (VCC), U16.20 (VCC), U17.2 (OE1), U17.3 (OE2), U17.9 (Mr), U17.19 (S1), U17.20 (VCC), U18.20 (VCC), U19.16 (VCC), X1.14 (Vcc)
/A0: U4.19 (Q0), U7.10 (A0), U9.2 (D0)
/A1: U4.18 (Q1), U7.9 (A1), U9.3 (D1)
/A2: U4.17 (Q2), U7.8 (A2), U9.4 (D2)
/A3: U4.16 (Q3), U7.7 (A3), U9.5 (D3)
/A4: U4.15 (Q4), U7.6 (A4), U9.6 (D4)
/A5: U4.14 (Q5), U7.5 (A5), U9.7 (D5)
/A6: U4.13 (Q6), U7.4 (A6), U9.8 (D6)
/A7: U4.12 (Q7), U7.3 (A7), U9.9 (D7)
/A8: U1.21 (P2.0(A8)), U7.25 (A8), U10.2 (D0)
/A9: U1.22 (P2.1(A9)), U7.24 (A9), U10.3 (D1)
/A10: U1.23 (P2.2(A10)), U7.21 (A10), U10.4 (D2)
/A11: U1.24 (P2.3(A11)), U7.23 (A11), U10.5 (D3)
/A12: U1.25 (P2.4(A12)), U7.2 (A12), U10.6 (D4)
/A13: U1.26 (P2.5(A13)), U7.26 (A13), U10.7 (D5)
/A14: U1.27 (P2.6(A14)), U7.1 (A14), U10.8 (D6)
/A15: U1.28 (P2.7(A15)), U3.2 (M1), U7.20 (~CE)
/CBuf0: U18.19 (Q0), U19.2 (I0a)
/CBuf1: U18.18 (Q1), U19.5 (I0b)
/CBuf2: U18.17 (Q2), U19.14 (I0c)
/CBuf3: U18.16 (Q3), U19.11 (I0d)
/CBuf4: U18.15 (Q4), U19.3 (I1a)
/CBuf5: U18.14 (Q5), U19.6 (I1b)
/CBuf6: U18.13 (Q6), U19.13 (I1c)
/CBuf7: U18.12 (Q7), U19.10 (I1d)
/CL0: U16.19 (Q0), U17.16 (IO7)
/CL1: U16.18 (Q1), U17.4 (IO6)
/CL2: U16.17 (Q2), U17.15 (IO5)
/CL3: U16.16 (Q3), U17.5 (IO4)
/CL4: U16.15 (Q4), U17.14 (IO3)
/CL5: U16.14 (Q5), U17.6 (IO2)
/CL6: U16.13 (Q6), U17.13 (IO1)
/CL7: U16.12 (Q7), U17.7 (IO0)
/Col0: U15.19 (Q0), U18.2 (D0)
/Col1: U15.18 (Q1), U18.3 (D1)
/Col2: U15.17 (Q2), U18.4 (D2)
/Col3: U15.16 (Q3), U18.5 (D3)
/Col4: U15.15 (Q4), U18.6 (D4)
/Col5: U15.14 (Q5), U18.7 (D5)
/Col6: U15.13 (Q6), U18.8 (D6)
/Col7: U15.12 (Q7), U18.9 (D7)
/D0: U1.39 (P0.0(AD0)), U4.2 (D0), U7.11 (D0), U12.2 (D0)
/D1: U1.38 (P0.1(AD1)), U4.3 (D1), U7.12 (D1), U12.3 (D1)
/D2: U1.37 (P0.2(AD2)), U4.4 (D2), U7.13 (D2), U12.4 (D2)
/D3: U1.36 (P0.3(AD3)), U4.5 (D3), U7.15 (D3), U12.5 (D3)
/D4: U1.35 (P0.4(AD4)), U4.6 (D4), U7.16 (D4), U12.6 (D4)
/D5: U1.34 (P0.5(AD5)), U4.7 (D5), U7.17 (D5), U12.7 (D5)
/D6: U1.33 (P0.6(AD6)), U4.8 (D6), U7.18 (D6), U12.8 (D6)
/D7: U1.32 (P0.7(AD7)), U4.9 (D7), U7.19 (D7), U12.9 (D7)
/GA0: U5.18 (B0), U8.18 (B0), U9.19 (Q0), U14.10 (A0)
/GA1: U5.17 (B1), U8.17 (B1), U9.18 (Q1), U14.9 (A1)
/GA2: U5.16 (B2), U8.16 (B2), U9.17 (Q2), U14.8 (A2)
/GA3: U5.15 (B3), U8.15 (B3), U9.16 (Q3), U14.7 (A3)
/GA4: U5.14 (B4), U9.15 (Q4), U11.19 (Q0), U14.6 (A4)
/GA5: U5.13 (B5), U9.14 (Q5), U11.18 (Q1), U14.5 (A5)
/GA6: U5.12 (B6), U9.13 (Q6), U11.17 (Q2), U14.4 (A6)
/GA7: U5.11 (B7), U9.12 (Q7), U11.16 (Q3), U14.3 (A7)
/GA8: U6.18 (B0), U10.19 (Q0), U11.15 (Q4), U14.25 (A8)
/GA9: U6.17 (B1), U10.18 (Q1), U11.14 (Q5), U14.24 (A9)
/GA10: U6.16 (B2), U10.17 (Q2), U11.13 (Q6), U14.21 (A10)
/GA11: U6.15 (B3), U10.16 (Q3), U11.12 (Q7), U14.23 (A11)
/GA12: U6.14 (B4), U8.14 (B4), U10.15 (Q4), U14.2 (A12)
/GA13: U6.13 (B5), U8.13 (B5), U10.14 (Q5), U14.26 (A13)
/GA14: U6.12 (B6), U8.12 (B6), U10.13 (Q6), U14.1 (A14)
/GD0: U11.2 (D0), U12.19 (Q0), U13.2 (D0), U14.11 (D0), U15.2 (D0), U16.2 (D0)
/GD1: U11.3 (D1), U12.18 (Q1), U13.3 (D1), U14.12 (D1), U15.3 (D1), U16.3 (D1)
/GD2: U11.4 (D2), U12.17 (Q2), U13.4 (D2), U14.13 (D2), U15.4 (D2), U16.4 (D2)
/GD3: U11.5 (D3), U12.16 (Q3), U13.5 (D3), U14.15 (D3), U15.5 (D3), U16.5 (D3)
/GD4: U11.6 (D4), U12.15 (Q4), U13.6 (D4), U14.16 (D4), U15.6 (D4), U16.6 (D4)
/GD5: U11.7 (D5), U12.14 (Q5), U13.7 (D5), U14.17 (D5), U15.7 (D5), U16.7 (D5)
/GD6: U11.8 (D6), U12.13 (Q6), U13.8 (D6), U14.18 (D6), U15.8 (D6), U16.8 (D6)
/GD7: U11.9 (D7), U12.12 (Q7), U13.9 (D7), U14.19 (D7), U15.9 (D7), U16.9 (D7)
/MA0: U2.4 (MA0), U5.3 (A1)
/MA1: U2.5 (MA1), U5.4 (A2)
/MA2: U2.6 (MA2), U5.5 (A3)
/MA3: U2.7 (MA3), U5.6 (A4)
/MA4: U2.8 (MA4), U5.7 (A5)
/MA5: U2.9 (MA5), U5.8 (A6)
/MA6: U2.10 (MA6), U5.9 (A7)
/MA7: U2.11 (MA7), U6.2 (A0)
/MA8: U2.12 (MA8), U6.3 (A1)
/MA9: U2.13 (MA9), U6.4 (A2)
/MA10: U2.14 (MA10), U6.5 (A3)
/MA11: U2.15 (MA11), U6.6 (A4)
/MA12: U2.16 (MA12)
/MA13: U2.17 (MA13)
/P1.0: U1.1 (P1.0(T2)), U2.33 (D0), U13.19 (Q0)
/P1.1: U1.2 (P1.1(T2_EX)), U2.32 (D1), U13.18 (Q1)
/P1.2: U1.3 (P1.2), U2.31 (D2), U13.17 (Q2)
/P1.3: U1.4 (P1.3), U2.30 (D3), U13.16 (Q3)
/P1.4: U1.5 (P1.4), U2.29 (D4), U13.15 (Q4)
/P1.5: U1.6 (P1.5(MOSI)), U2.28 (D5), U13.14 (Q5)
/P1.6: U1.7 (P1.6(MISO)), U2.27 (D6), U13.13 (Q6)
/P1.7: U1.8 (P1.7(SCK)), U2.26 (D7), U13.12 (Q7)
/RA0: U2.38 (RA0), U8.2 (A0)
/RA1: U2.37 (RA1), U8.3 (A1)
/RA2: U2.36 (RA2), U8.4 (A2)
/RA3: U2.35 (RA3), U8.5 (A3)
/RA4: U2.34 (RA4)
CCLK: U2.21 (CLK), U3.9 (M8)
CHAROE: U3.22 (M16), U8.19 (CE), U11.1 (OE)
COLOR: U3.24 (M17), U5.2 (A0)
CRTCOE: U3.18 (M13), U5.19 (CE), U6.19 (CE)
Charset: U1.12 (P3.2(*INT0)), U8.6 (A4)
DE: U2.18 (DE), U3.11 (M9)
DispEn: U19.15 (~EN)
GND: C1.2, C3.2, J1.4 (GND), J2.2, J2.10, J3.2, J4.5, J4.6, J4.7, J4.8, J4.10, R1.2, U1.20 (GND), U2.1 (GND), U2.3 (LPSTB), U2.22 (R/~W), U2.25 (~CS), U3.10 (GND), U3.23 (GND), U3.31 (GND), U4.1 (OE), U4.10 (GND), U5.10 (GND), U6.7 (A5), U6.10 (GND), U7.14 (GND), U8.10 (GND), U9.10 (GND), U10.10 (GND), U11.10 (GND), U12.10 (GND), U13.10 (GND), U14.14 (GND), U14.20 (~CE), U14.22 (~OE), U15.1 (OE), U15.10 (GND), U16.1 (OE), U16.10 (GND), U17.10 (GND), U18.1 (OE), U18.10 (GND), U19.8 (GND), X1.7 (GND)
GWE\: U3.19 (M14), U12.1 (OE), U14.27 (~WE)
HS: U2.39 (HS), U3.12 (M10)
HSYNC: J4.13, U3.1 (M1)
LOADAD: U3.8 (M6), U9.11 (Load), U10.11 (Load), U12.11 (Load)
LOADCHR: U3.20 (M15), U11.11 (Load)
LOADDAT: U3.6 (I/O/GCK2), U13.11 (Load)
LoadCharline: U3.42 (I/O/GTS1), U16.11 (Load)
LoadCol: U3.7 (I/O/GCK3), U15.11 (Load)
LoadSr: U3.14 (M12), U3.40 (I/O/GTS2), U17.1 (S0), U18.11 (Load)
unnamed: C1.1, Crystal1.1, U1.18 (XTAL2)
unnamed: C2.2, R1.1, SW1.1, U1.9 (RST)
unnamed: C3.1, Crystal1.2, U1.19 (XTAL1)
unnamed: J4.1, R2.2
unnamed: J4.2, R3.2
unnamed: J4.3, R4.2
unnamed: R2.1, U19.4 (Qa)
unnamed: R3.1, U19.7 (Qb)
unnamed: R4.1, U19.12 (Qc)
unnamed: R5.1, U19.9 (Qd)
unnamed: U1.29 (*PSEN), U7.22 (~OE)
unnamed: U1.30 (ALE/*PROG), U4.11 (Load)
unnamed: U10.12 (Q7), U13.1 (OE)
unnamed: U17.8 (Q0), U19.1 (S)
OE_ADR: U9.1 (OE), U10.1 (OE)
PixClk: U3.5 (I/O/GCK1), X1.8 (OUT)
PixClkO: U3.43 (M4), U17.12 (Cp)
RD\: U1.17 (P3.7(*RD))
RXD: J3.3, U1.10 (P3.0(RXD))
Screen: U1.13 (P3.3(*INT1)), U6.8 (A6), U8.8 (A6)
T0: U1.14 (P3.4(T0)), U2.24 (RS), U10.9 (D7)
T1: U1.15 (P3.5(T1)), U2.23 (E)
TCK: J2.1, U3.17 (TCK)
TDI: J2.9, U3.15 (TDI)
TDO: J2.3, U3.30 (TDO)
TMS: J2.5, U3.16 (TMS)
TXD: J3.4, U1.11 (P3.1(TXD))
VS: U2.40 (VS), U3.13 (M11)
VSYNC: J4.14, U3.44 (M2)
WR\: U1.16 (P3.6(*WR)), U3.3 (M2), U7.27 (~WE)

Board: 2 copper layers, 34 parts (0 on the bottom side), 141 nets, no tracks yet.

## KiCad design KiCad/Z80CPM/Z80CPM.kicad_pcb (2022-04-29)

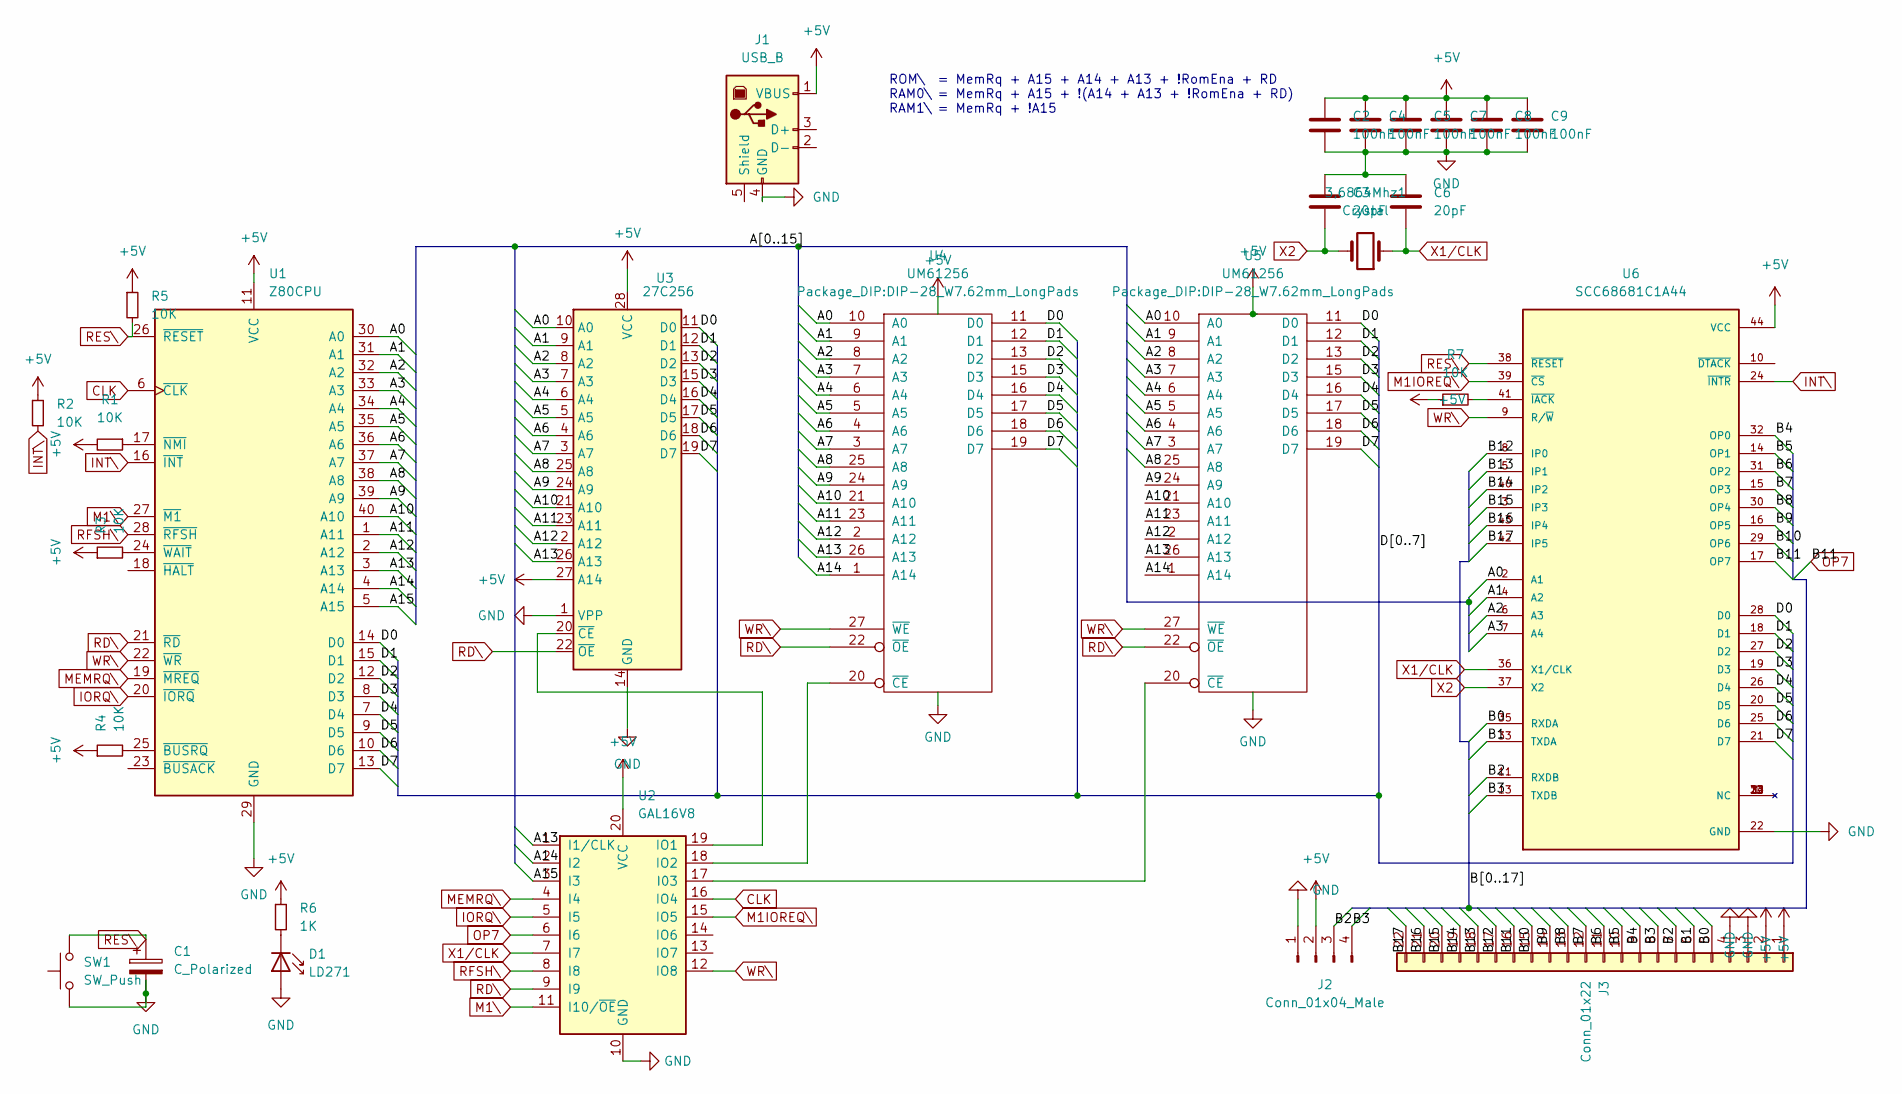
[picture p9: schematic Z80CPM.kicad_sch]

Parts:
3,6864Mhz1: Crystal; Crystal_HC18-U_Vertical
C1: C_Polarized; CP_Radial_D5.0mm_P2.50mm
C2, C4, C5, C7, C8, C9: 100nF; PinHeader_1x02_P2.54mm_Vertical
C3, C6: 20pF; PinHeader_1x02_P2.54mm_Vertical
D1: LD271; LED_D5.0mm_IRGrey
J1: USB_B; USB_B_Lumberg_2411_02_Horizontal
J2: Conn_01x04_Male; PinHeader_1x04_P2.54mm_Vertical
J3: Conn_01x22; PinHeader_1x22_P2.54mm_Vertical
R1, R2, R3, R4, R5, R7: 10K; R_Axial_DIN0207_L6.3mm_D2.5mm_P10.16mm_Horizontal
R6: 1K; R_Axial_DIN0204_L3.6mm_D1.6mm_P1.90mm_Vertical
SW1: SW_Push; C_Rect_L7.5mm_W6.5mm_P5.00mm
U1: Z80CPU; DIP-40_W15.24mm_Socket_LongPads
U2: GAL16V8; DIP-20_W7.62mm_Socket_LongPads
U3: 27C256; DIP-28_W15.24mm
U4, U5: UM61256; DIP-28_W7.62mm_LongPads
U6: SCC68681C1A44; PLCC-44_THT-Socket; PARTREV _1

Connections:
+5V: C2.1, C4.1, C5.1, C7.1, C8.1, C9.1, J1.1 (VBUS), J2.2, J3.1, J3.2, R1.2, R2.1, R3.1, R4.1, R5.1, R6.1, R7.1, U1.11 (VCC), U2.20 (VCC), U3.27 (A14), U3.28 (VCC), U4.28 (VCC), U5.28 (VCC), U6.44 (VCC)
/A0: U1.30 (A0), U3.10 (A0), U4.10 (A0), U5.10 (A0), U6.2 (A1)
/A1: U1.31 (A1), U3.9 (A1), U4.9 (A1), U5.9 (A1), U6.4 (A2)
/A2: U1.32 (A2), U3.8 (A2), U4.8 (A2), U5.8 (A2), U6.6 (A3)
/A3: U1.33 (A3), U3.7 (A3), U4.7 (A3), U5.7 (A3), U6.7 (A4)
/A4: U1.34 (A4), U3.6 (A4), U4.6 (A4), U5.6 (A4)
/A5: U1.35 (A5), U3.5 (A5), U4.5 (A5), U5.5 (A5)
/A6: U1.36 (A6), U3.4 (A6), U4.4 (A6), U5.4 (A6)
/A7: U1.37 (A7), U3.3 (A7), U4.3 (A7), U5.3 (A7)
/A8: U1.38 (A8), U3.25 (A8), U4.25 (A8), U5.25 (A8)
/A9: U1.39 (A9), U3.24 (A9), U4.24 (A9), U5.24 (A9)
/A10: U1.40 (A10), U3.21 (A10), U4.21 (A10), U5.21 (A10)
/A11: U1.1 (A11), U3.23 (A11), U4.23 (A11), U5.23 (A11)
/A12: U1.2 (A12), U3.2 (A12), U4.2 (A12), U5.2 (A12)
/A13: U1.3 (A13), U2.1 (I1/CLK), U3.26 (A13), U4.26 (A13), U5.26 (A13)
/A14: U1.4 (A14), U2.2 (I2), U4.1 (A14), U5.1 (A14)
/A15: U1.5 (A15), U2.3 (I3)
/B0: J3.5, U6.35 (RXDA)
/B1: J3.6, U6.33 (TXDA)
/B2: J2.3, J3.7, U6.11 (RXDB)
/B3: J2.4, J3.8, U6.13 (TXDB)
/B4: J3.9, U6.32 (OP0)
/B5: J3.10, U6.14 (OP1)
/B6: J3.11, U6.31 (OP2)
/B7: J3.12, U6.15 (OP3)
/B8: J3.13, U6.30 (OP4)
/B9: J3.14, U6.16 (OP5)
/B10: J3.15, U6.29 (OP6)
/B12: J3.17, U6.8 (IP0)
/B13: J3.18, U6.5 (IP1)
/B14: J3.19, U6.40 (IP2)
/B15: J3.20, U6.3 (IP3)
/B16: J3.21, U6.43 (IP4)
/B17: J3.22, U6.42 (IP5)
/D0: U1.14 (D0), U3.11 (D0), U4.11 (D0), U5.11 (D0), U6.28 (D0)
/D1: U1.15 (D1), U3.12 (D1), U4.12 (D1), U5.12 (D1), U6.18 (D1)
/D2: U1.12 (D2), U3.13 (D2), U4.13 (D2), U5.13 (D2), U6.27 (D2)
/D3: U1.8 (D3), U3.15 (D3), U4.15 (D3), U5.15 (D3), U6.19 (D3)
/D4: U1.7 (D4), U3.16 (D4), U4.16 (D4), U5.16 (D4), U6.26 (D4)
/D5: U1.9 (D5), U3.17 (D5), U4.17 (D5), U5.17 (D5), U6.20 (D5)
/D6: U1.10 (D6), U3.18 (D6), U4.18 (D6), U5.18 (D6), U6.25 (D6)
/D7: U1.13 (D7), U3.19 (D7), U4.19 (D7), U5.19 (D7), U6.21 (D7)
CLK: U1.6 (~CLK), U2.16 (IO4)
GND: C1.2, C2.2, C3.1, C4.2, C5.2, C6.1, C7.2, C8.2, C9.2, D1.2 (A), J1.4 (GND), J2.1, J3.3, J3.4, SW1.1, U1.29 (GND), U2.10 (GND), U3.1 (VPP), U3.14 (GND), U4.14 (GND), U5.14 (GND), U6.22 (GND)
INT\: R2.2, U1.16 (~INT), U6.24 (~INTR)
IORQ\: U1.20 (~IORQ), U2.5 (I5)
M1IOREQ\: U2.15 (IO5), U6.39 (~CS)
M1\: U1.27 (~M1), U2.11 (I10/~OE)
MEMRQ\: U1.19 (~MREQ), U2.4 (I4)
unnamed: D1.1 (K), R6.2
unnamed: R3.2, U1.24 (~WAIT)
unnamed: R4.2, U1.25 (~BUSRQ)
unnamed: R7.2, U6.41 (~IACK)
unnamed: R1.1, U1.17 (~NMI)
unnamed: U2.17 (I03), U5.20 (~CE)
unnamed: U2.18 (IO2), U4.20 (~CE)
unnamed: U2.19 (IO1), U3.20 (~CE)
OP7: J3.16, U2.6 (I6), U6.17 (OP7)
RD\: U1.21 (~RD), U2.9 (I9), U3.22 (~OE), U4.22 (~OE), U5.22 (~OE)
RES\: C1.1, R5.2, SW1.2, U1.26 (~RESET), U6.38 (~RESET)
RFSH\: U1.28 (~RFSH), U2.8 (I8)
WR\: U1.22 (~WR), U2.12 (IO8), U4.27 (~WE), U5.27 (~WE), U6.9 (R/~W)
X1/CLK: 3,6864Mhz1.1, C6.2, U2.7 (I7), U6.36 (X1/CLK)
X2: 3,6864Mhz1.2, C3.2, U6.37 (X2)

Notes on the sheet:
ROM\ = MemRq + A15 + A14 + A13 + !RomEna + RD RAM0\ = MemRq + A15 + !(A14 + A13 + !RomEna + RD) RAM1\ = MemRq + !A15

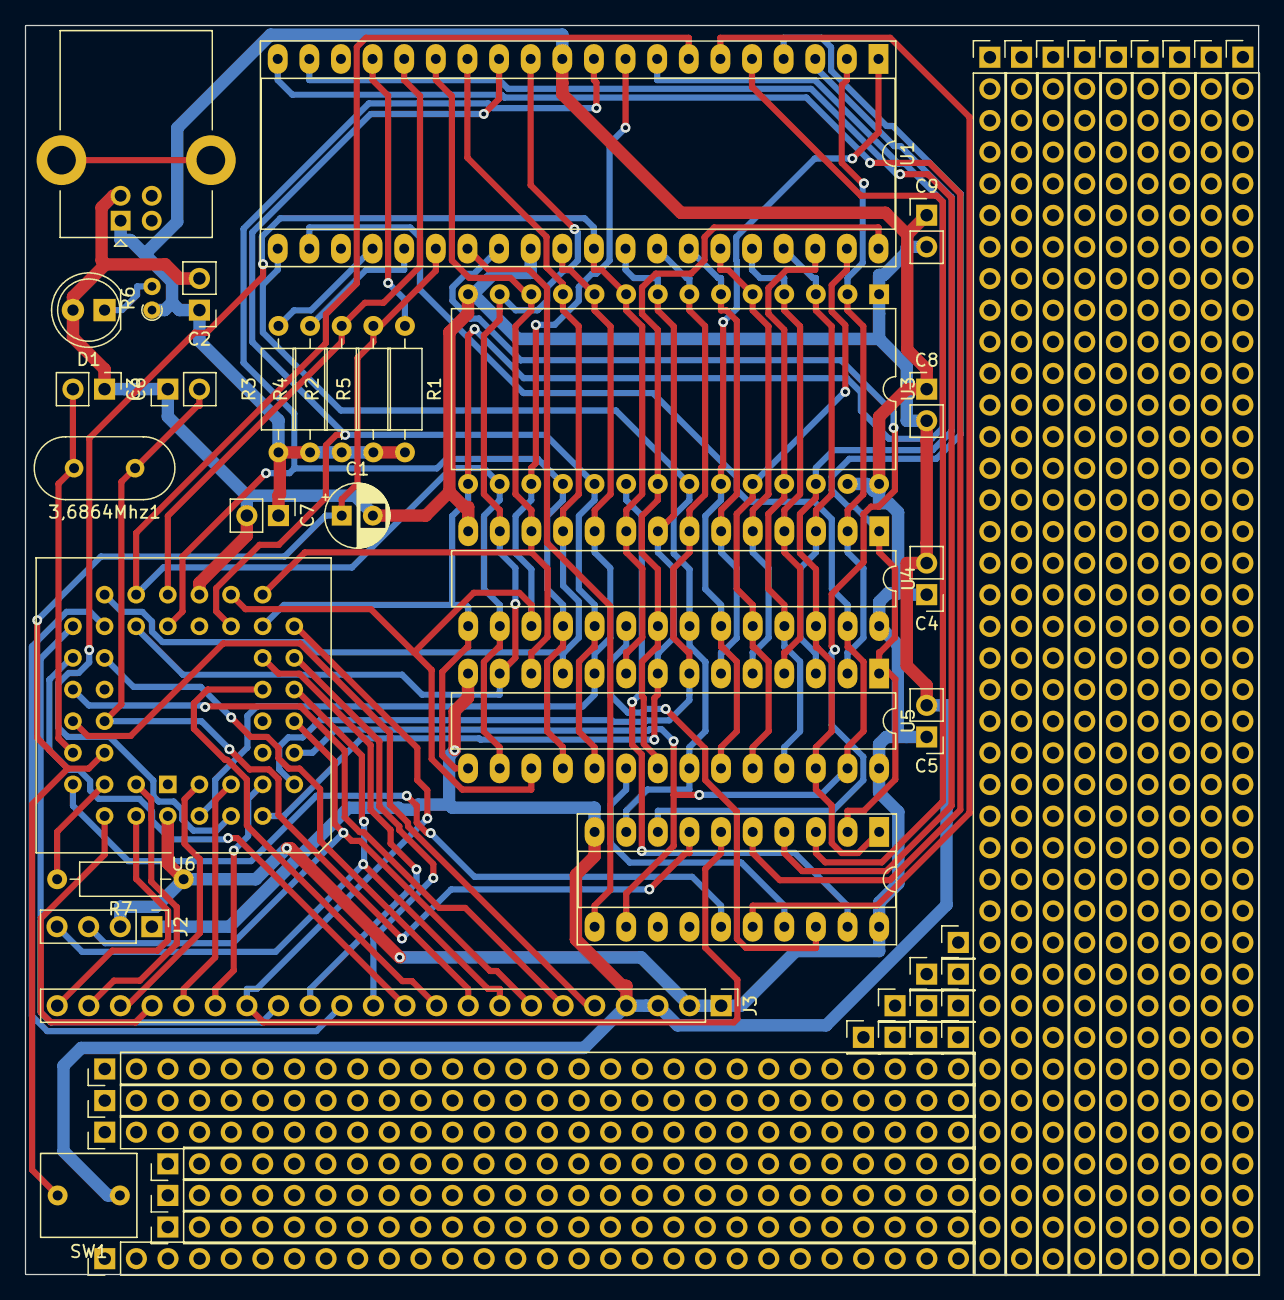
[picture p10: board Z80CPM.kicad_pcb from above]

Board: 2 copper layers, 99.1 x 100.3 mm, 28 parts (0 on the bottom side), 64 nets.

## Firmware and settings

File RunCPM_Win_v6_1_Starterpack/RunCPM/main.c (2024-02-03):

/*
		RunCPM - Execute 8bit CP/M applications on modern computers
		Copyright (c) 2016 - Marcelo Dantas

		Extensive debugging/testing by Tom L. Burnett
		Debugging/testing and new features by Krzysztof Klis
		DOS and Posix ports added by Krzysztof Klis

		Best operating system ever by Gary Kildall, 40 years ago
		I was 9 at that time and had no idea what a computer was
*/

// Only build this code if not on Arduino
#ifndef ARDUINO

/* globals.h must be the first file included - it defines the bare essentials */
#include "globals.h"

/* Any system specific includes should go here - this will define system functions used by the abstraction */

/* all the RunCPM includes must go after the system specific includes */

/*
abstraction.h - Adds all system dependent calls and definitions needed by RunCPM
This should be the only file modified for portability. Any other file
shoud be kept the same.
*/

#ifdef _WIN32
#include "abstraction_vstudio.h"
#else
#include "abstraction_posix.h"
#endif

// AUX: device configuration
#ifdef USE_PUN
FILE* pun_dev;
int pun_open = FALSE;
#endif

// PRT: device configuration
#ifdef USE_LST
FILE* lst_dev;
int lst_open = FALSE;
#endif

#include "ram.h"		// ram.h - Implements the RAM
#include "console.h"	// console.h - Defines all the console abstraction functions
#include "cpu.h"		// cpu.h - Implements the emulated CPU
#include "disk.h"		// disk.h - Defines all the disk access abstraction functions
#include "host.h"		// host.h - Custom host-specific BDOS call
#include "cpm.h"		// cpm.h - Defines the CPM structures and calls
#ifdef CCP_INTERNAL
#include "ccp.h"		// ccp.h - Defines a simple internal CCP
#endif

int main(int argc, char* argv[]) {

#ifdef DEBUGLOG
	_sys_deletefile((uint8*)LogName);
#endif


	_host_init(argc, &argv[0]);
	_console_init();
  _clrscr();
	_puts("CP/M Emulator \e[1mv" VERSION "\e[0m   by \e[1mMarcelo Dantas\e[0m\r\n");
	_puts("----------------------------------------------\r\n");
	_puts("     running    on   [\e[1mWindows\e[0m]\r\n");
	_puts("     compiled with   [\e[1mMinGW64-GCC v13.2.0\e[0m]\r\n");  
	_puts("     Revision        [\e[1m" GLREV "\e[0m]\r\n");

#ifdef HASLUA
	_puts("       with Lua scripting support\r\n");
#endif
	_puts("----------------------------------------------\r\n");

	_puts("BIOS              at [\e[1m0x");
	_puthex16(BIOSjmppage);
//	_puts(" - ");
	_puts("\e[0m]\r\n");

	_puts("BDOS              at [\e[1m0x");
	_puthex16(BDOSjmppage);
	_puts("\e[0m]\r\n");

	_puts("CCP " CCPname " at [\e[1m0x");
	_puthex16(CCPaddr);
	_puts("\e[0m]\r\n");

#if BANKS > 1
	_puts("Banked Memory        [\e[1m");
	_puthex8(BANKS);
	_puts("\e[0m]banks\r\n");
#else
	_puts("Banked Memory        [\e[1m");
	_puthex8(BANKS);
	_puts("\e[0m]bank\r\n");
#endif

	_puts("----------------------------------------------");

	while (TRUE) {
		_puts(CCPHEAD);
		_PatchCPM();		// Patches the CP/M entry points and other things in
		Status = 0;
#ifdef CCP_INTERNAL
		_ccp();
#else
		if (!_sys_exists((uint8*)CCPname)) {
			_puts("Unable to load CP/M CCP.\r\nCPU halted.\r\n");
			break;
		}
		_RamLoad((uint8*)CCPname, CCPaddr);	// Loads the CCP binary file into memory
		Z80reset();			// Resets the Z80 CPU
		SET_LOW_REGISTER(BC, _RamRead(DSKByte));	// Sets C to the current drive/user
		PC = CCPaddr;		// Sets CP/M application jump point
		Z80run();			// Starts simulation
#endif
		if (Status == 1)	// This is set by a call to BIOS 0 - ends CP/M
			break;
#ifdef USE_PUN
		if (pun_dev)
			_sys_fflush(pun_dev);
#endif
#ifdef USE_LST
		if (lst_dev)
			_sys_fflush(lst_dev);
#endif
	}

   	_puts("\r\n");
	_console_reset();

	return(0);
}

#endif

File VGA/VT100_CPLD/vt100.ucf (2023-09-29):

#PACE: Start of Constraints generated by PACE

#PACE: Start of PACE I/O Pin Assignments
#NET "OE_DAT"	SLOW;
#NET "OE_ADR"	SLOW;
#NET "OE_RAM"	SLOW;
#NET "LOADDAT"	SLOW;
#NET "LOADAD"	SLOW;
#NET "OE_RAM"	SLOW;
#NET "WE_RAM"	SLOW;
#NET "CHAROE"	SLOW;
#NET "CRTCOE"	SLOW;

NET "HSYNC"		LOC = "P1";
NET "A15"		LOC = "P2";
NET "WR"			LOC = "P3";
NET "RD"			LOC = "P4";
NET "PCLK"  	LOC = "P5"; 
NET "LOADDAT" 	LOC = "P6"; 
NET "LOADCOL"	LOC = "P7"; 
NET "LOADAD"	LOC = "P8"; 
NET "CCLK"		LOC = "P9"; 
NET "DE"			LOC = "P11"; 
NET "HS"			LOC = "P12"; 
NET "VS"			LOC = "P13"; 
NET "LOADSR"	LOC = "P14"; 
NET "CRTCOE"	LOC = "P18"; 
NET "WE_RAM"	LOC = "P19"; 
NET "LOADCHR"	LOC = "P20"; 
NET "CHAROE"	LOC = "P22"; 
NET "DISPEN"	LOC = "P24"; 
NET "OE_ADR"	LOC = "P25";
NET "LOADCOLB"	LOC = "P26";
NET "OE_DAT"	LOC = "P27";
NET "OE_RAM"	LOC = "P28";
NET "T0"			LOC = "P29";
#NET "ALE"		LOC = "P30";

NET "VSYNC"		LOC = "P44";
NET "PIXCLKO"	LOC = "P43";
NET "LCHRLINE" LOC = "P42";
NET "LOADSRIN" LOC = "P40";

#PACE: Start of PACE Area Constraints

#PACE: Start of PACE Prohibit Constraints

#PACE: End of Constraints generated by PACE

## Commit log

2022-04-29 tidy up
    [8039.PRT, BIOSINT.PRT, DEBUGGER.PRT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]
2022-04-29 pcb bottom
2023-05-03 VGA + SDCard
    [VT100.kicad_pcb, VT100.kicad_sch]
2023-06-09 VT100 MCU, KiCad and CPLD
    [VT100.kicad_pcb, VT100.kicad_sch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]
2023-10-09 mode mode Please enter the commit message for your changes. Lines starting
    [vt100_pad.csv]
